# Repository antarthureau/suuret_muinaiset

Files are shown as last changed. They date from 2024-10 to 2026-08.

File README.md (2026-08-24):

# Suuret Muinaiset system (V3)

## Overview

The installation has three units. Each unit is one creature: LONG, SMALL or
SEASHELL. Each unit has a Teensy 4.0 microcontroller.

Each unit plays its own audio file. It drives its own amplifier and speaker. It
also calculates its own LED brightness from the audio signal.

LONG is the leader. It is green, and it has the only RTC. SMALL (yellow) and
SEASHELL (red) are followers.

All three units use the same compiled firmware. At start-up, each unit reads
three hardware ID strap pins. The pin that reads HIGH selects the role.
Therefore the role is not a build option.

The firmware is in `src/teensy_codebase/teensy_code_v3`.

`teensy_code_v1` and `teensy_code_v2` stay in the repository for reference. The
Raspberry Pi 5 and Pure Data system is not in use. Its code stays in `src`.

## Unit hardware

Each unit is an IP65 enclosure. It contains the equipment that follows.

- Teensy 4.0 microcontroller on a custom motherboard. The motherboard connects
  the power, the relays, the LED PWM output, Serial3, the volume potentiometer
  input and the 4-LED status array.
- Teensy Audio Shield with an SGTL5000 codec. The micro SD card slot is below
  the Teensy board. The card holds the WAV file for that unit.
- Dual-channel 150 W audio amplifier (WONDOM AA-AB32221). Each unit uses one
  channel only. If the channel becomes defective, connect the spare channel.
  Do not replace the board immediately.
- 36V DC PSU (LOP-300-36). It supplies the amplifier. Relay 2 switches it.
- 12V DC PSU (PSK-15D-12-T). It supplies the Teensy, the motherboard and the
  LED strip. It is always on.
- 4-relay board (Velleman WPM400). Two relays are in use. Relay 1 connects the
  amplifier output to the speaker. Relay 2 connects the 220V AC supply to the
  36V DC PSU. Two spare relays are on the same board.
- DS3231 RTC module on I2C. LONG only.
- Outdoor speaker (Dayton WP8BT).
- LED strip on the speaker grille. A MOSFET on the motherboard drives it.
  The PWM output of the Teensy controls the MOSFET.

During sleep, only the 12V DC PSU indicator is on.

The enclosure has these connectors:

- USB-A for the upload and the serial console.
- EtherCON for Serial3, on underground CAT6 to the other units.
- A second EtherCON for the PWM and LED output. On LONG it also carries the
  volume potentiometer signal.
- PowerCON for the amplifier output to the speaker.
- 230V AC mains input. Wago connectors distribute it in the enclosure.

A pressure-compensating vent and a silica gel tank keep the humidity and the
pressure stable in each enclosure.

## Site wiring

Each unit is in its own enclosure on site. Underground CAT6 connect the three enclosures.
A custom Y-cable divides the serial run from the leader etherCON to the underground CAT6 lines
connecting to the follower units etherCON.

Each unit gets a 230V AC supply comes to its enclosure.

## Audio signal path

The Teensy reads the WAV file for its unit from the SD card. `config.h` gives
the file names in `cfg::FILE_LONG`, `cfg::FILE_SMALL` and `cfg::FILE_SEASHELL`.
The names on the card are `LONG.WAV`, `SMALL.WAV` and `SEASHELL.WAV`. A FAT
file system ignores the letter case.

The source files are in `src/audio/mono/`. `TESTLOOP.WAV` is also in that
folder for bench tests.

The SGTL5000 codec on the Audio Shield converts the audio. The Audio Shield has
a 3.5 mm TRS minijack output. This output goes to an RCA input on the amplifier
board.

The amplifier output goes through a terminal block to Relay 1. When the unit is
awake, Relay 1 connects the output to a PowerCON socket (NAC3FPX-TRUE1). The
mating plug on the speaker cable outside the enclosure is NAC3M-TRUE1-L.

### Why the audio files have one channel

The WAV files are 16-bit PCM at 44.1 kHz. They have one channel (mono).

The first masters had two channels. The firmware read only channel 0 from them.
This did no damage. But it used more bandwidth than necessary.

The samples in a WAV file are in this sequence: L, R, L, R. Therefore the unit
must read the full file from the SD card to get channel 0. A file with two
channels used 176 KB/s of SD card bandwidth. But it gave only 88 KB/s of audio.

New masters with one channel decreased the necessary bandwidth by 50 percent.
This change corrected a high CPU load and audio noise on site. The correction
was in the audio files, not in the firmware.

The first files with two channels are in `src/audio/stereo/`. Keep them for
reference only. Do not copy them to an SD card.

`src/audio/make_mono.sh` makes the one-channel files again from the two-channel
files. It keeps channel 0 without a change to the samples.

### SD card and interrupts

`AudioPlaySdWav` reads the SD card in the audio interrupt. It does not read the
card in `loop()`. Two results are important:

- A slow main loop does not stop the audio. It makes the light irregular.
- Other code that uses the SD card can cause a conflict with the interrupt.

`AudioEngine::retryInit()` therefore does not operate while audio plays.
`SD.begin()` starts the same card that the interrupt reads.

The Teensy 4.0 has no internal SDIO socket. Therefore the card must be in the
socket of the Audio Shield, on the SPI bus. A slow SD card is the most probable
cause of an audio failure.

## Light signal path

`AudioAnalyzePeak` and `AudioAnalyzeRMS` objects connect to the same playback
stream in the audio object graph. Refer to `AudioEngine`.

Each 25 milliseconds (`cfg::PWM_UPDATE_MS`), the controller reads the current
level. `cfg::PEAK_MODE` selects the peak value or the RMS value. The controller
multiplies the level by a range value (`rangePwm_`). The keys `>` and `<`
change this range during operation. Then the controller writes the result to
the 8-bit PWM output on pin 6.

The PWM frequency is 20 kHz (`cfg::PWM_FREQ_HZ`). This frequency is above the
audible range. The default frequency of the Teensy 4 is approximately 4.5 kHz.
That frequency is audible, and it goes into the audio circuit through the
common ground.

The PWM signal goes on CAT6 through the second EtherCON connector to the LED
daughter board. An IRL520 MOSFET on that board controls the current in the 12V
LED strip. The result is the same as the analog PCB of the first system. But
the firmware calculates it.

## Firmware

### Files

The firmware in use is in `src/teensy_codebase/teensy_code_v3`:

```
config.h            pins, times, status codes and protocol constants
StatusLeds.h/.cpp   4-LED binary status display
Relays.h/.cpp       amplifier and speaker relay sequence
AudioEngine.h/.cpp  SGTL5000 codec, SD card playback, peak and RMS analyzers
RtcClock.h/.cpp     DS3231 clock (leader only)
SerialLink.h/.cpp   addressed frames with a checksum, on Serial3
Controller.h/.cpp   role detection, leader and follower state machines
teensy_code_v3.ino  entry point, makes one Controller
```

The `Controller` object holds one instance of each subsystem. It is the only
global object.

`ledzCtrl.h` and `sysCtrl.h` are also in this folder. They are old files from
V2. No file includes them. They are not part of the firmware in use.

`RTC_setup_code/RTC_setup_code.ino` is a separate sketch. Use it to test or to
program a DS3231 module away from the installation.

### Build

1. Start the Arduino IDE with Teensyduino.
2. Select Tools > Board > Teensy 4.0.
3. Select the port of the unit.
4. Click Upload.

The board selection is important. `Watchdog_t4.h` declares `WDT_T4` and `WDOG1`
for the i.MX RT chip only. Teensyduino keeps the 3.x boards and the 4.x boards
in the same `avr` platform folder. Therefore a build with a Teensy 3.x board
gives this error: `'WDOG1' was not declared in this scope`. The library is
correctly installed, but the header is empty for that board.

All three units use the same compiled sketch.

### Compile-time flags

The flags are at the top of `config.h`.

```
USE_WATCHDOG   1  the hardware watchdog resets the unit after 15 seconds
                  of a hang. Set to 0 only if the WDT_T4 library is absent.
                  It must be 1 on site.
AUDIO_TRACE    0  the leader sends an audio-health line each second while
                  audio plays. Set to 1 for diagnostics only. It must be 0
                  on site.
```

`cfg::AUDIO_MEMORY_BLOCKS` (120) sets the size of the audio buffer pool. One
block is 128 samples, or 2.9 milliseconds of audio. The value is larger than
necessary. This gives protection against a slow read from the SD card.

### Role detection

`Controller::detectRole()` reads the three strap pins one time at start-up:

```
pin 32 HIGH  ->  LEADER (LONG)
pin 30 HIGH  ->  SMALL
pin 28 HIGH  ->  SEASHELL
```

The pins use the internal pulldown resistors. Therefore a disconnected strap
reads LOW. If no pin reads HIGH, the unit becomes the leader and sends a
warning on the USB console.

## Teensy pinout

| Pin | Function |
|---|---|
| 0, 1 | Reserved for USB Serial. Do not connect. |
| 2-5 | Status LEDs 1-4 (binary array, LED 1 = MSB) |
| 6 | PWM output to the LED strip driver |
| 7, 8 | Not in use (Serial2 is possible) |
| 9, 12 | Not in use |
| 10 | SD card CS |
| 11 | SD card MOSI |
| 13 | SD card SCK |
| 14 | Serial3 RX (SMALL and SEASHELL only) |
| 15 | Serial3 TX (LONG only) |
| 16 | Relay 1, speaker |
| 17 | Relay 2, 36V PSU and amplifier |
| 18 | RTC SDA (I2C, LONG only) |
| 19 | RTC SCL (I2C, LONG only) |
| 20 | Audio Shield LRCLK |
| 21 | Audio Shield BCLK |
| 22 / A8 | Volume potentiometer analog input |
| 23 | Audio Shield MCLK |
| 28 | Hardware ID strap, SEASHELL |
| 30 | Hardware ID strap, SMALL |
| 32 | Hardware ID strap, LONG (leader) |

Serial3 and the PWM line go through EtherCON chassis sockets (NE8FDPU-TOP) on
CAT6.

The RJ45 pinout of the serial link is opposite at the two ends of the run.
Therefore the Tx of the leader goes to the Rx of the follower. One end is 1 Rx,
2 GND, 3 Tx. The other end is 1 Tx, 2 GND, 3 Rx. Pins 4 to 8 are not in use.

Refer to page 8 of `documentation/manual/manual v1.0.pdf` before you make a
connector again.

PWM and volume RJ45 on LONG: 1 NC, 2 GND, 3 NC, 4 +3.3V, 5 A8 potentiometer
signal, 6 NC, 7 PWM+, 8 PWM-.

PWM RJ45 on SMALL and SEASHELL: 1 to 6 NC, 7 PWM+, 8 PWM-.

## Serial3 link protocol

The three units share one Serial3 link at 9600 baud. The forward line goes from
the Tx of the leader to the Rx of the two followers. The return line goes from
the Tx of the two followers to the Rx of the leader. Therefore only the return
line is common to more than one transmitter.

Each frame has an address and a checksum:

```
#<addr><cmd><arg>*<XX>\n
```

`addr` is `0` for the two followers, `1` for SMALL, `2` for SEASHELL, or `L`
for the leader. Only status replies use `L`.

`cmd` is one command character. `arg` is an optional short ASCII payload.

`XX` is the XOR of all the characters between `#` and `*`, in two hexadecimal
digits.

`SerialLink::poll()` makes one frame at a time and does not block. It ignores a
frame with an overflow, with no `*`, or with an incorrect checksum. A `#`
character always starts a new frame.

### Command characters

| Char | Command | Notes |
|---|---|---|
| `P` | Play | The leader sends this one time for each round, to keep the units synchronized |
| `X` | Stop | Stops the audio and sets the PWM output to zero |
| `W` | Wake | Does the relay wake sequence: 36V PSU on, then speaker on |
| `S` | Sleep | Does the relay sleep sequence: speaker off, then 36V PSU off |
| `H` | Heartbeat | Leader to followers each 5 seconds. `arg` is `1` or `0` for the awake state |
| `R` | Report request | The leader sends this to one follower. That follower answers one time |
| `s` | Status reply | Follower to leader only. `arg` is `role,awake,playing,cpu_temp` |
| `B` | Reboot | The leader sends this, then each unit resets after 3 seconds |
| `V` | Set volume | `arg` is a value between 0.0 and 1.0 |
| `+` / `-` | Volume up or down | Steps of 0.1 |
| `>` / `<` | PWM range up or down | Steps of 25, between 0 and 255 |
| `K` | Volume knob on or off | Lets the potentiometer control the volume |
| `?` | Help | Prints the command list on the USB console only |

### How the two followers share one line

The two followers transmit on the same return line. Three rules prevent two
transmissions at the same time.

- Only `R` causes a follower to transmit. The follower does all other commands
  and stays quiet.
- The leader never sends `R` to address `0`. It always sends `R` to `1` or to
  `2`. The other follower reads the address, and stops.
- The automatic poll asks SMALL, waits 150 milliseconds
  (`cfg::REPORT_STAGGER_MS`), then asks SEASHELL.

A request and a reply together are approximately 25 milliseconds at 9600 baud.
Therefore the 150 millisecond interval is sufficient.

If two replies do come at the same time, the checksum fails. The leader ignores
the frame. The next automatic poll is 20 seconds later.

## USB serial console

Connect the USB cable to a unit. Then open a serial terminal at 9600 baud. The
Arduino Serial Monitor, PuTTY or other serial tools are all satisfactory.
The enclosure can be open or closed.

This is the primary method to communicate with one unit. It does not use the
Serial3 link.

### Single-key commands

```
P  play          W  wake      R  report    +  volume up     >  PWM range up
X  stop          S  sleep     B  reboot    -  volume down   <  PWM range down
K  volume knob on/off         ?  help
```

On the leader, the keys `P X W S + - > < B` go to the followers first. Then the
leader does the command. Therefore the volume keys and the PWM keys change all
three units together.

The keys `R`, `K` and `?` operate on the local unit only. On a follower, all
keys operate on that follower only.

`R` prints the role, the WAV file name, the RTC time on the leader, the awake
and playing states, the volume, the PWM range, the number of rounds, the codec
and SD card status, and the CPU temperature.

### Line commands

A line command starts with `:`. Enter or a pause of 200 milliseconds completes
it.

Clock commands:

```
:settime YYYY MM DD HH MM SS   set the RTC directly
:synctime                      set the RTC to the compile time of the sketch
:time                          print the RTC time
```

The clock commands are for the leader. On a follower the RTC is not
initialized, and the command does nothing.

`:synctime` is a last option only. The compile time is old by the interval
between the build and the upload.

Follower status commands. The leader accepts these commands only:

```
:small      request a status report from SMALL
:seashell   request a status report from SEASHELL
:status     request a report from the two followers, one after the other
```

The follower answers a moment later. The reply prints on the console of the
leader in this form:

```
Status from SMALL: awake YES, playing NO, CPU 41.7 C
```

The leader also requests these reports automatically each 20 seconds.

### Volume

The volume control is not linear. `AudioControlSGTL5000::volume()` writes the
headphone register of the codec. That register is in steps of 0.5 dB, from
+12 dB to -51.5 dB.

```
1.0  ->  +12.0 dB      0.6  ->  -13.5 dB   (the value on site)
0.9  ->   +6.0 dB      0.5  ->  -20.0 dB
0.8  ->   -0.5 dB      0.3  ->  -32.5 dB
0.7  ->   -7.0 dB      0.1  ->  -45.5 dB
```

Each step of 0.1 is therefore approximately 6.5 dB. A value of 1.0 gives 12 dB
of gain, not the level of the audio file.

The unit does not keep the volume value. At each start-up the volume returns to
`cfg::DEFAULT_VOLUME`.

## Status LED codes

The 4-LED array on each motherboard shows a binary code. LED 1 is the most
significant bit. LED 4 is the least significant bit. In the LEDs column, `1` is
an LED that is on.

| Code | LEDs | Name | Meaning |
|---|---|---|---|
| 1 | 0001 | SLEEP | asleep, normal |
| 2 | 0010 | AWAKE | awake, no audio |
| 3 | 0011 | SD_ERR | no SD card |
| 4 | 0100 | CODEC_ERR | no SGTL5000 codec |
| 5 | 0101 | RTC_ERR | no clock (leader only) |
| 6 | 0110 | LINK_ERR | no heartbeat for 90 seconds (followers only) |
| 7 | 0111 | REBOOT | the unit starts again |
| 8 | 1000 | PLAYING | audio plays |

Code 1 during the sleep hours, and sound and light during the awake hours, are
the normal condition.

### Fault codes at start-up

The unit shows the fault codes SD_ERR, CODEC_ERR and RTC_ERR at start-up only.
It does not keep them on the display.

`setup()` finds these faults. At the end of `setup()`, the unit flashes each
fault code for 4 seconds. Then the normal state display starts.

The flash is necessary. A continuous code looks the same as a normal state
code. Also, the first cycle of `loop()` writes to the LED array immediately.

A unit that operates for some hours therefore shows a normal code. This happens
even if the SD card is defective. To read the fault codes again, start the unit
again. Refer to "Read the fault codes at start-up".

## Daily schedule

The leader reads the RTC each 30 seconds. If the awake state must change, the
leader sends `W` or `S` to the two followers. The heartbeat also carries the
awake state.

`config.h` has `cfg::START_HOUR = 8` and `cfg::END_HOUR = 20`. The units are
awake from 08:00 to 20:00. The printed manual gives the first schedule of 07:00
to 22:00. Correct one of the two documents.

To change the schedule, set `START_HOUR` and `END_HOUR` in `config.h`. Then
upload the firmware to the leader. The followers do not read an RTC. They take
the awake state from the leader.

The units stay energized during sleep. Only the 36V amplifier PSU and the
speaker relay go off. The MCU, the watchdog and the Serial3 link continue for
24 hours each day.

## Diagnostics

Set `AUDIO_TRACE` to `1` in `config.h`. The leader then sends one line each
second while audio plays. The default value is `0`.

```
t=<position ms> mem=<peak audio blocks> cpu=<peak audio ISR load %>
```

Read the output as follows:

- If `mem` increases to the limit of 120, the SD card is too slow.
- If `t` does not increase by about 1000 between two lines, the SD card is too
  slow.
- If `mem` and `t` stay correct during an audio fault, the digital circuit is
  correct. The cause is then in the analog circuit after the codec.

Record the output to a file. Use time stamps. Do not use the monitor window
only. An intermittent fault needs the lines before the event and after the
event. It also needs a count of the events before you make a change.

Set `AUDIO_TRACE` to `0` again after the test.

## Troubleshooting

### Read the fault codes at start-up

1. Connect the USB cable of the unit to a computer.
2. Open the enclosure.
3. Press `B` on the USB console. As an alternative, remove the power. Then
   apply the power again.
4. Look at the LED array during the start-up.
5. The unit flashes each fault code for 4 seconds.
6. If the unit flashes no code, the codec, the SD card and the RTC are
   serviceable.

### Code 3 (SD_ERR): no SD card

1. Make sure that the card is fully in the slot. The slot is below the Teensy
   board.
2. Make sure that the card has a FAT32 file system.
3. Make sure that the card has the correct file name for that unit: `LONG.WAV`,
   `SMALL.WAV` or `SEASHELL.WAV`.
4. Use the files from `src/audio/mono/`. Do not use the files from
   `src/audio/stereo/`.
5. The unit tries to find the card again each 3 seconds. It stops after 20
   tries, or approximately 60 seconds after the start-up. Therefore install the
   card again, then start the unit again.

### Code 4 (CODEC_ERR): no codec

1. Remove the Teensy Audio Shield. Then install it again on the header.
2. Examine the solder joints on the shield and on the header pins.
3. Examine the 3.3V supply to the shield.

### Code 5 (RTC_ERR): no clock

1. Examine the I2C wiring on pins 18 and 19. The leader only shows this code.
2. Examine the DS3231 module.
3. Connect the USB cable. If the leader reports lost power at each start-up,
   replace the coin cell.

### Code 6 (LINK_ERR): no heartbeat

1. Examine the CAT6 cable between the leader and the follower.
2. Examine the Serial3 connections at the two ends. The Tx and Rx pins are
   opposite at the two ends. Pin 2 is GND.
3. Make sure that the leader has power and operates. A follower shows code 6
   if the leader stops.
4. Send `:small` or `:seashell` on the USB console of the leader. If the
   follower answers, the cable is serviceable in the two directions.
5. If the follower does not answer, examine the power and the LED array of that
   follower.

### One unit makes no sound

1. Do the procedure "Read the fault codes at start-up".
2. Make sure that the two PSU indicators are on during the awake hours.
3. Examine the minijack cable from the Audio Shield to the RCA input of the
   amplifier.
4. Press `P` on the USB console. If the unit then plays, the schedule is the
   cause. Refer to "The unit sleeps at the incorrect time".
5. If the amplifier channel is defective, connect the second channel of the
   same board.

### The audio has noise or interruptions

1. Make sure that the SD card has the files from `src/audio/mono/`. A file with
   two channels needs two times more bandwidth.
2. Set `AUDIO_TRACE` to `1` in `config.h`. Then build the firmware and upload
   it.
3. Record the console output to a file for one hour. Use time stamps.
4. Write down the time of each audio fault.
5. Read the trace. Refer to "Diagnostics".
6. If the trace shows that the SD card is too slow, replace the SD card.
7. If the trace stays correct, connect headphones to the minijack output. Then
   listen again.
8. If the noise continues in the headphones, the cause is in the codec or its
   connections. Examine the Audio Shield.
9. If the headphones are correct, the cause is in the amplifier or the speaker.
10. Set `AUDIO_TRACE` to `0` again after the test.

### The unit sleeps at the incorrect time

1. Connect the USB cable to the leader.
2. Send `:time` on the USB console.
3. If the time is incorrect, send `:settime YYYY MM DD HH MM SS` with the
   correct values.
4. If the leader reports lost power at each start-up, replace the DS3231 coin
   cell.
5. Make sure that `START_HOUR` and `END_HOUR` in `config.h` are correct.

### Relay problems

1. Two of the four relays are in use. Relay 1 is the speaker. Relay 2 is the
   36V PSU.
2. If one relay becomes defective, connect one of the two spare relays on the
   same board.
3. If all four relays become defective, replace the board.

### The unit does not answer on USB, but the LEDs operate

1. The watchdog resets the unit after 15 seconds of a hang. Wait 20 seconds.
2. If the unit stays locked, the cause is probably the hardware. The main loop
   does not block.
3. Examine the USB cable and the USB connector.

### The build stops with an error

1. If the error is `'WDOG1' was not declared in this scope`, look at the board
   selection. It must be Teensy 4.0.
2. If the board selection is correct, install the WDT_T4 library. As an
   alternative, set `USE_WATCHDOG` to `0` for a test build.
3. Look at the full path in the error message. Make sure that it is the path of
   your local repository. A different copy of the sketch can have different
   values in `config.h`.
4. Close the Arduino IDE and open it again. The IDE can keep an old object file
   in its cache.

## Required toolkit

- Flat screwdriver 3 mm for the terminal blocks.
- Flat screwdriver 6 mm and Phillips 6 mm for the screws of the enclosures and general use.
- Multimeter for voltage and continuity tests: 230V AC, 12V DC, 36V DC.
- Phillips 000 and 00 screwdrivers, and 4 mm and 4.5 mm hex keys.
- Anti-static wrist strap.
- Wago connectors, wire and crocodile clips for temporary connections.
- 3.5 mm stereo headphones to listen to the Audio Shield output directly.
- A computer with a USB-A port, the Arduino IDE with Teensyduino, and a serial
  monitor.
- A long CAT6 test cable, or a cable tester, for the underground runs.

For workshop tests:

- An Arduino Uno R3 to program or test a DS3231 module. Refer to
  `RTC_setup_code`.
- An oscilloscope for signal analysis.
- A spare Teensy 4.0 to exchange components.
- A bench power supply for isolated tests.

## Warranty and support

Warranty period: 04.06.2025 to 04.06.2026.

Support during the warranty period: ahureau@pm.me, or the support technician on
site in Turku. The usual answer time is 24 to 48 hours.

## References

- `documentation/manual/manual v1.0.pdf` is the full technical manual. It has
  the block diagrams and the connector pinout charts. This README comes from
  that manual.
- `documentation/editable doc.drawio` and `editable doc v2.drawio` are the
  editable source diagrams.
- `documentation/3D prints stl files/` has the enclosure gaskets and the
  mounting parts.
- (UNUSED)`documentation/schematics v2.pdf` is for the analog envelope-follower PCB of
  the first Raspberry Pi system. It does not apply to this Teensy system. The
  firmware now calculates the light envelope.

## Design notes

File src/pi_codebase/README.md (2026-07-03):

# suuret_muinaiset system (V2)
## Overview
The installation runs on a single Raspberry Pi 5, replacing the previous three-unit Teensy-based system (LONG, SMALL, SEASHELL).
One Raspberry Pi 5 running Pure Data plays three audio files simultaneously (main.pd in pd_codebase), one file per creature, and drives both the speakers and the LED lighting (sound-to-light analog circuit) for all three units.

## Hardware/Software Requirements
Raspberry Pi 5 with onboard RTC and battery, used for the daily sleep/wake cycle.

Pure Data (Pd), run headless via pd -nogui. Login at desktop activated, so troubleshooting with mouse, keyboard and HDMI screen is possible.

zexy external library (installed via Deken), loaded in the patch with [declare -lib zexy].

HiFiBerry 8-channel DAC card, three of its outputs used for the three audio channels. LONG on DAC3, SMALL on DAC1, SEASHELL on DAC2, and DAC5/6 is a headphone out with a sum of all creatures.

Neutrik transformers, used twice per channel: once locally to balance the signal for transmission, and once at each remote creature to convert back to unbalanced before the amp.

Cat6 cable, run underground, carrying the balanced signal to each creature's site.

Amplifier and speaker at each creature site.

Custom analog PCB per creature: envelope-follower circuit based on TL072 and TL071 op-amps with an IRL540 MOSFET, converting that creature's audio amplitude into LED strip brightness.

12V LED strip per creature (final installation voltage).

2× SMPS per unit: 36VDC for the amplifier and 12VDC for the LED circuit PCB and LED strips. On the LONG unit, the PCB also carries an on-board Traco DC-DC converter providing 5V to power the Raspberry Pi from the 12V supply rail; this component is not populated on the SMALL and SEASHELL boards.

## Signal path

Pd plays three looping audio files, one per creature, out through three channels of the HiFiBerry DAC. Each unbalanced line passes through a Neutrik transformer to balance it for the long underground Cat6 run to that creature's location. At the far end, a second Neutrik transformer converts the signal back to unbalanced before it reaches that creature's amplifier and speaker.

## Audio-to-light circuit

Each creature has a custom PCB (ordered from JLCPCB) that converts its audio channel's amplitude into a brightness level for its 12V LED strip, independently of the speaker signal path.

Signal path through the circuit:

Audio arrives at an RCA connector and passes through a 1µF capacitor (AC coupling, blocking any DC offset) into a bias network — a 100kΩ/100kΩ resistor divider sets a +6V virtual midpoint from the 12V supply, centering the signal for single-supply op-amp operation.

The first TL072 half (U1A) buffers the input. The second TL072 half (U1B) amplifies the signal; gain is set by a 1MΩ feedback resistor and a 100kΩ trimmer potentiometer.

A 1N4148 diode half-wave rectifies the amplified AC signal into a positive envelope voltage. Two 100kΩ trimmer potentiometers control attack time (how fast the envelope rises with loud transients) and decay time (how slowly it falls when sound stops). A 4.7µF capacitor holds the peak level between transients.

A TL071 (U2) buffers the envelope voltage, isolating the capacitor from the output stage.

An IRL540 power MOSFET (Q1) is driven through a 100Ω gate resistor. A 10kΩ pull-down resistor on the gate ensures the MOSFET turns fully off when the signal drops to zero. The MOSFET switches the 12V LED strip current in proportion to the envelope voltage.

Power input is protected against reverse polarity by a 1N4007 diode. On the LONG unit PCB only, a Traco DC-DC converter provides a regulated 5V output used to power the Raspberry Pi from the 12V supply rail. This component is not populated on the SMALL and SEASHELL boards.

## Pure Data patch

Main patch: pd_codebase/main.pd, run in nogui mode.

Loops playback continuously; prints a status line at the start of each loop, captured by the terminal/log rather than the patch itself doing timestamping.

Elapsed time within each loop is tracked via zexy's realtime object, converted to mn:ss:ms via expr and sprintf, and reset at the start of each playback cycle (roughly every 6 minutes).

Remote control of the running patch (e.g. via Pd's netreceive) is possible but not yet implemented.

## Sleep/Wake schedule

The Pi sleeps and wakes itself daily using its onboard RTC and battery, fully powering off rather than suspending. This requires POWER_OFF_ON_HALT=1 in the bootloader config, checked with sudo rpi-eeprom-config.

The script /home/mike/sleep_pi.sh sets the next wake alarm and shuts the system down:

```
#!/bin/bash
echo 0 > /sys/class/rtc/rtc0/wakealarm
echo $(date -d "tomorrow 08:00" +%s) > /sys/class/rtc/rtc0/wakealarm
/usr/sbin/shutdown -h now
```

It must use the full path /usr/sbin/shutdown, since cron runs with a minimal PATH that doesn't include /usr/sbin.

The script is triggered daily by root's crontab (sudo crontab -e). Current entry: 00 22 * * * /home/mike/sleep_pi.sh, meaning cron fires the sleep script at 22:00, and the script sets the wake alarm for 08:00 the next day. When changing sleep or wake times, update both the cron line and the date string in the script together, leaving a few minutes of margin between the cron trigger and the wake target.

### Autostart

The Pi boots into the desktop automatically (autologin enabled via raspi-config, System Options, Boot/Auto Login, Desktop Autologin). On desktop load, labwc reads ~/.config/labwc/autostart, which contains:

```
lxterminal -e "/usr/bin/pd -nogui -alsa -alsaadd snd_rpi_hifiberry_dac8x -outchannels 8 -noadc -nomidi -r 44100 -blocksize 512 -audiobuf 25 -noprefs -open /home/mike/Documents/suuret_muinaiset/pd_codebase/main.pd" &
```

The trailing & is required so labwc doesn't wait for Pd to exit before finishing desktop startup. This opens a visible terminal running Pd, so a technician with a screen and keyboard can see live output directly, while remote access via Pi Connect or SSH works the same regardless.

### Daily cycle

08:00, Pi wakes, boots to desktop, Pd autostarts via labwc.

08:00 to 22:00, Pd runs continuously, looping playback through all three channels.

22:00, cron fires sleep_pi.sh, which sets the next wake alarm and shuts the Pi down fully.

22:00 to 08:00, Pi is fully powered off.

## Network Access

The Pi has three network interfaces, each serving a different purpose:

wlan0 — onboard WiFi, configured as a permanent hidden-SSID access point. Used for on-site wireless maintenance without opening the enclosure. No internet access.

eth0 — wired ethernet, static IP. Used for a direct on-site cable connection when WiFi isn't practical or reliable enough.

wlan1 — USB WiFi dongle (D-Link AC13U). Connects outward to an external network (e.g. a phone hotspot) to bring the Pi online, which is required for Pi Connect remote support.

Pick the option below that matches your situation.

### Option 1: WiFi access point (on-site, no cable needed)

SSID: HUOLTO-NETT (hidden, not broadcast)
Security: WPA2
Password: see project credentials
Static IP: 10.42.0.1

On your laptop, open WiFi settings and manually join the hidden network HUOLTO-NETT (you'll need to enter the SSID by name since it won't appear in scan results). Set your laptop's WiFi interface to a static IP on the same subnet, e.g. 10.42.0.50 / 255.255.255.0.

Then:
```
ssh mike@10.42.0.1
```

### Option 2: Wired ethernet (on-site, direct cable)

Static IP: 10.42.1.2

Connect a Cat6 cable directly between your laptop's ethernet port (or USB/Thunderbolt-to-RJ45 adapter) and the Pi's ethernet port. Set your laptop's ethernet interface to a static IP on the same subnet, e.g. 10.42.1.50 / 255.255.255.0.

Then:
```
ssh mike@10.42.1.2
```

Useful when WiFi conditions on-site are poor, or as a fallback if the access point config is ever broken and needs fixing from scratch.

### Option 3: Internet access for remote support (wlan1)

If remote support from the development team is needed, wlan1 must be connected to an internet-providing WiFi network (e.g. a phone hotspot). Get in touch with the development team in advance so everyone involved can plan for a maintenance session.

Once you have SSH access via Option 1 or 2 above, connect wlan1:
```
sudo nmcli device wifi connect "hotspot_name" password "hotspot_password" ifname wlan1
```

If the hotspot password contains special characters, use single quotes instead of double quotes around it, otherwise the shell may misinterpret characters like $ or ( ) before nmcli ever sees them:
```
sudo nmcli device wifi connect "hotspot_name" password 'hotspot_password' ifname wlan1
```

If the target network doesn't show up in a scan (common with iPhone hotspots, which only broadcast while the Personal Hotspot screen is actively open), create the connection manually instead:
```
sudo nmcli connection add type wifi ifname wlan1 con-name "hotspot_name" ssid "hotspot_name"
sudo nmcli connection modify "hotspot_name" wifi-sec.key-mgmt wpa-psk
sudo nmcli connection modify "hotspot_name" wifi-sec.psk 'hotspot_password'
sudo nmcli connection up "hotspot_name"
```

Pi Connect becomes available to the development team automatically once wlan1 has internet access. Check status with:
```
rpi-connect status
```

Note: the D-Link dongle is currently running on its default in-kernel driver (rtl8xxxu), not the DKMS RTL8192EU driver. This works for now but hasn't been validated for long-term stability — see Key learnings for follow-up.

## Pure Data - Command Line Options

The installation launches Pd headless with explicit audio configuration flags set in the autostart command, rather than relying on Pd's saved preferences. This ensures consistent behaviour across reboots and system changes.

Current launch flags:

```
pd -nogui -alsa -alsaadd snd_rpi_hifiberry_dac8x -outchannels 8 -noadc -nomidi -r 44100 -blocksize 512 -audiobuf 25 -noprefs -open /home/mike/Documents/suuret_muinaiset/pd_codebase/main.pd
```

Flag summary:

| Flag | Purpose |
|---|---|
| `-nogui` | Headless operation |
| `-alsa` | Force ALSA audio API |
| `-alsaadd snd_rpi_hifiberry_dac8x` | Pin HiFiBerry DAC8x by name (stable across reboots) |
| `-outchannels 8` | Open all 8 DAC channels |
| `-noadc` | Disable audio input |
| `-nomidi` | Disable MIDI |
| `-r 44100` | Sample rate |
| `-blocksize 512` | DSP block size in samples |
| `-audiobuf 25` | Audio I/O buffer in milliseconds |
| `-noprefs` | Ignore saved Pd preferences; command line is authoritative |

Full reference for Pd command line options: https://puredata.info/docs/faq/commandline

## Toolkit required for maintenance

Screwdrivers to open/close boxes and fasten terminal blocks: flat 3mm, flat 6mm, Philips 6mm.

Multimeter to test voltage, current, and continuity.

Wago connectors and crocodile cables for temporary test connections.

A pair of headphones with minijack, to test audio output directly from the Pi (DAC 5/6).

HDMI cable, screen, keyboard and mouse, for direct access to the Pi's desktop on site.

Computer or laptop for SSH/Pi Connect access when remote troubleshooting is preferred over an on-site screen.

Ethernet cable (Cat6) and a USB/Thunderbolt-to-RJ45 adapter if your laptop lacks a built-in ethernet port, for wired on-site access.

A smartphone with hotspot to connect the Pi to the wifi, allowing remote control via Pi-Connect.

Long Cat6 testing cable or cable tester, for diagnosing the underground transformer runs.

Gaffer tape, zip ties, and miscellaneous crimping tools can be helpful.

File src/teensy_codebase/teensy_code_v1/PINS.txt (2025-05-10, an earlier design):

PINS:
    0 x (must be NC, used for USB Serial)
    1 x (must be NC, used for USB Serial)
    2 LED_1
    3 LED_2
    4 LED_3
    5 LED_4
    6 PWM_OUT (LED strip control)
    7 x (can be used as receiver for Serial2)
    8 x (can be used as transmitter for Serial2)
    9 x
    10 SDCARD_CS_PIN (SD card)
    11 SDCARD_MOSI_PIN (SD card)
    12 x
    13 SDCARD_SCK_PIN (SD card)
    14 RX3 (receive serial on SM/SS, x on LO)
    15 TX3 (send serial on LO, x on SM/SS)
    16 REL_2 (relay speaker)
    17 REL_1 (relay PSU/amp)
    18 SDA0 (RTC on LO, x on SM/SS)
    19 SCL0 (RTC on LO, x on SM/SS)
    20 LRCLK1 (audio)
    21 BCLK1 (audio)
    22 VOL_CTRL_PIN (analog volume ctrl)
    23 MCLK (audio)
    28 PLAYED_ID (2, SS)
    30 PLAYER_ID (1, SM)
    32 PLAYER_ID (0, LO)

  CODES:
    0 x
    1 asleep
    2 awake
    3 unable to access SD
    4 SGTL not found
    5
    6
    7 system reboot in 5seconds
    8 audio playback
    9
    10
    11
    12
    13 SGTL5000 not found
    14
    15

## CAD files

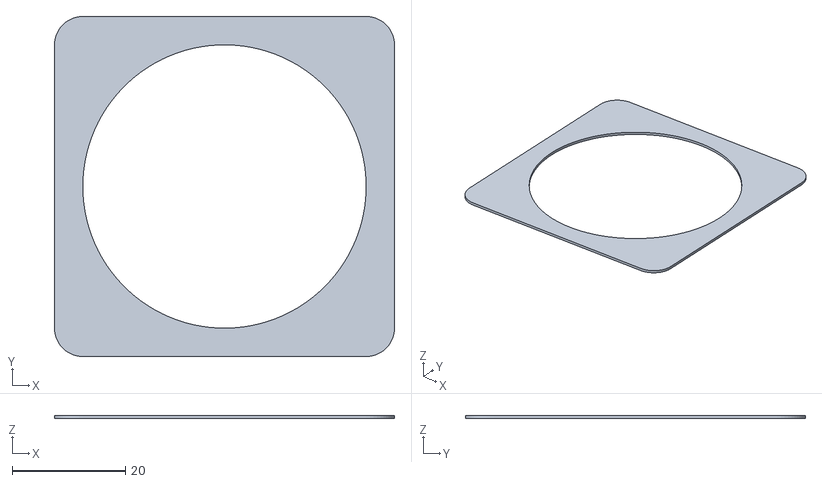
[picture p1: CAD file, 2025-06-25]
documentation/3D prints stl files/Sillica Gel Tank TPU Gasket.stl
60.0 x 60.0 x 0.6

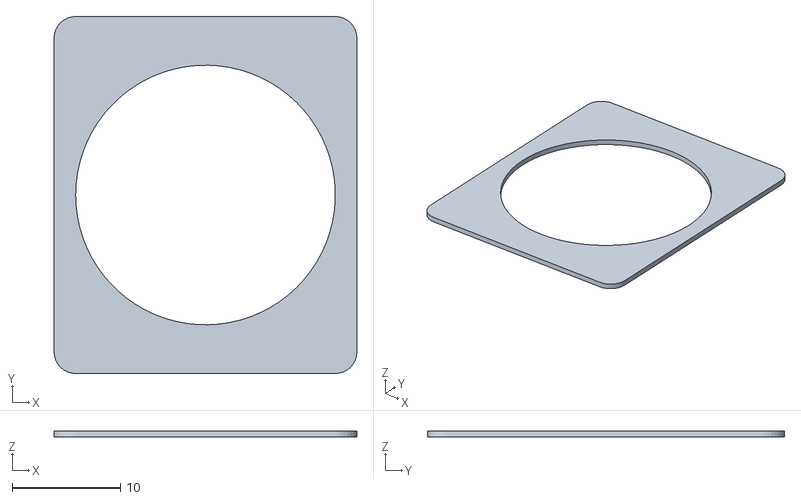
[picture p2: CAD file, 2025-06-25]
documentation/3D prints stl files/Ethercon TPU gasket.stl
28.0 x 33.0 x 0.6

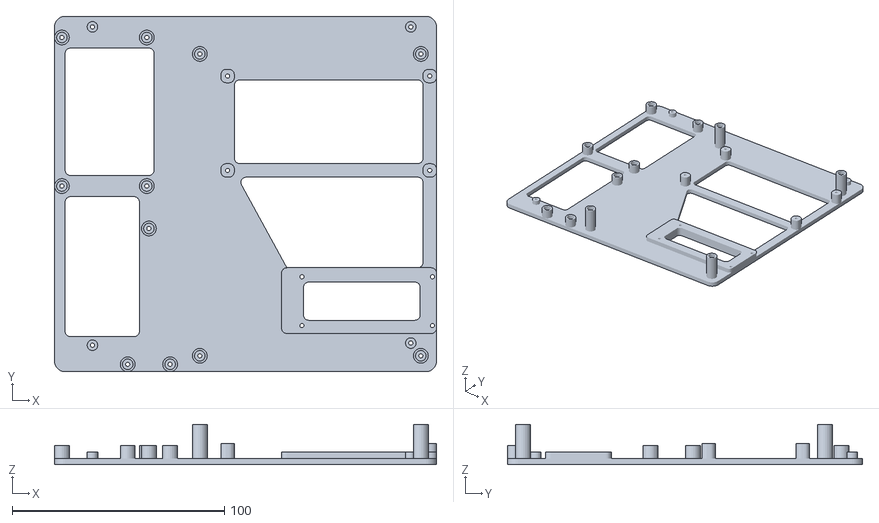
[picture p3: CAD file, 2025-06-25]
documentation/3D prints stl files/PETG Mounting Plate.stl
180.0 x 167.5 x 19.0

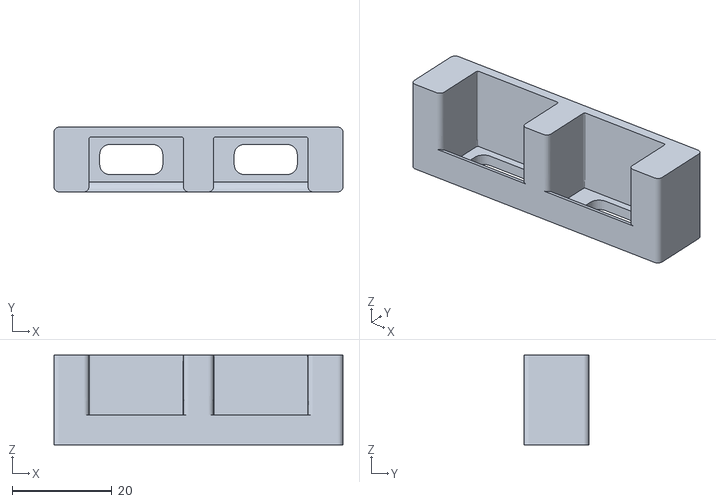
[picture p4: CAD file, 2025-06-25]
documentation/3D prints stl files/Double 3-ways Wago holder.stl
58.0 x 13.0 x 18.0

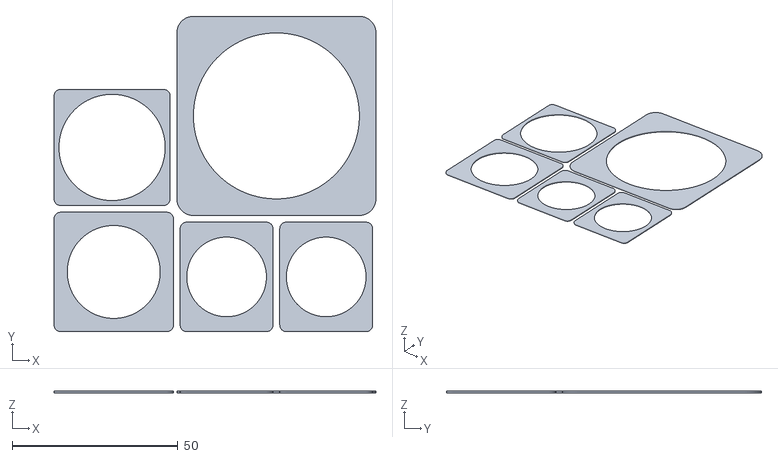
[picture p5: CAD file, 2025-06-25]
documentation/3D prints stl files/All TPU Gaskets.stl
97.0 x 95.0 x 0.6

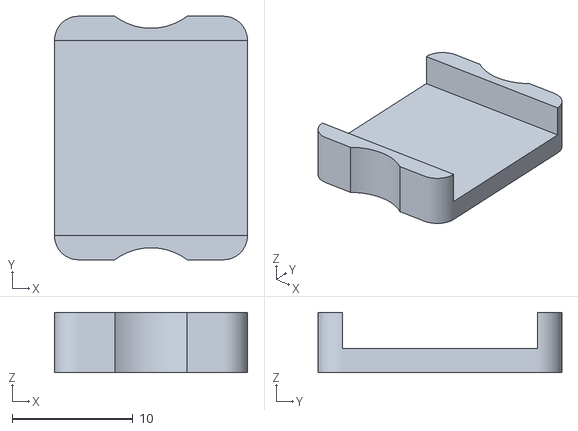
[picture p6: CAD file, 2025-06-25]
documentation/3D prints stl files/Motherboard relays connector cover.stl
16.0 x 20.2 x 5.00

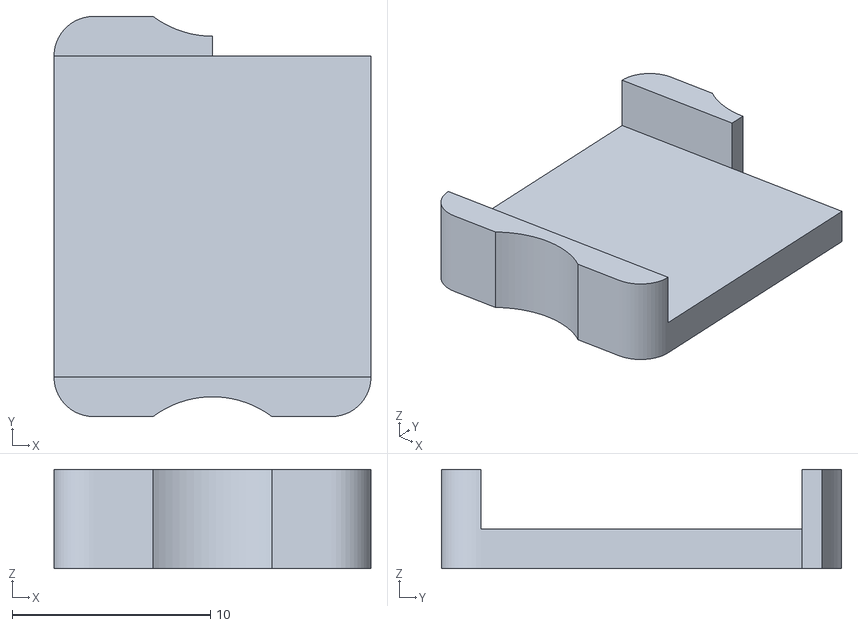
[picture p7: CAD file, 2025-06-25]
documentation/3D prints stl files/Relay board connector cover.stl
16.0 x 20.2 x 5.00

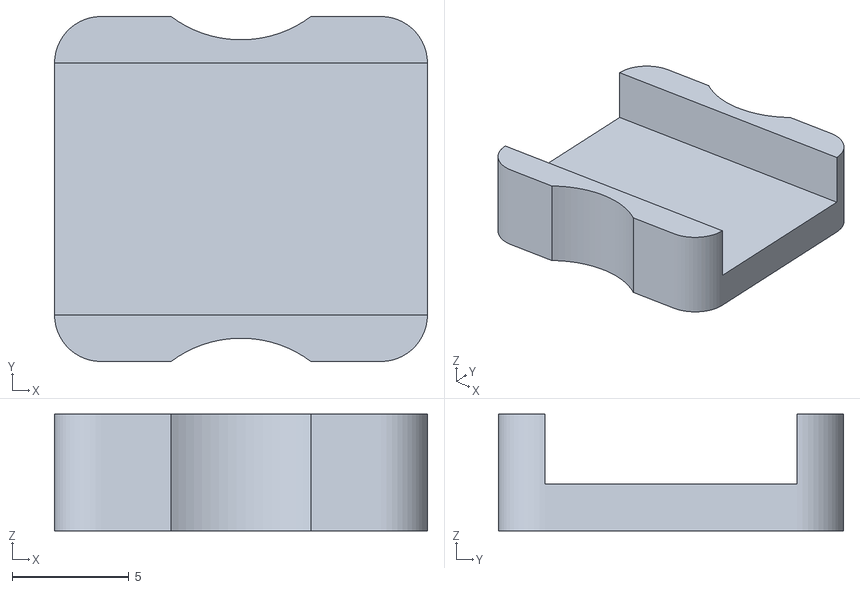
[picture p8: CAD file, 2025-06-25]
documentation/3D prints stl files/RTC cable connector cover.stl
16.0 x 14.8 x 5.00

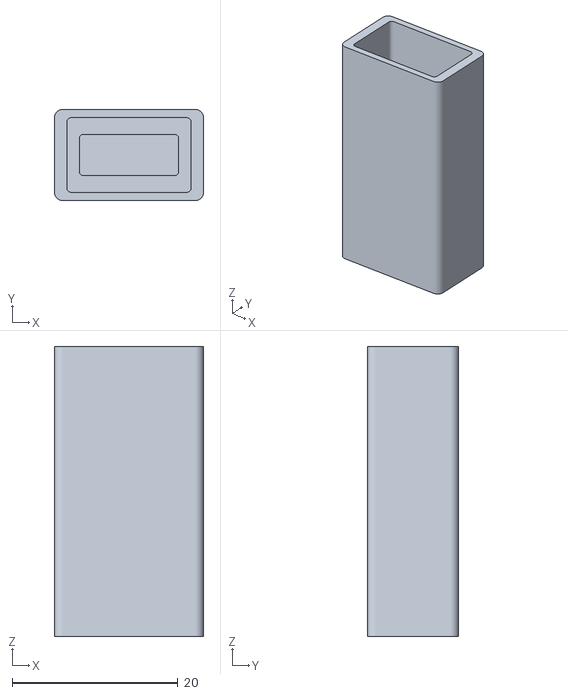
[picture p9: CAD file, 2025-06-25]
documentation/3D prints stl files/USB-A TPU cover.stl
18.0 x 11.0 x 35.0

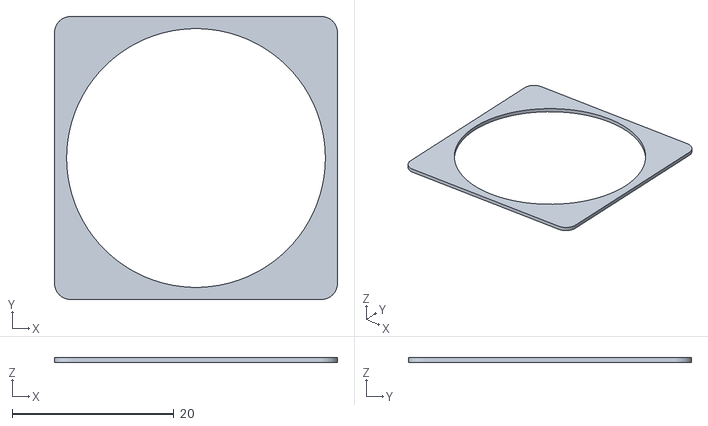
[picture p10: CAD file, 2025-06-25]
documentation/3D prints stl files/Pressure Vent TPU Gasket.stl
35.0 x 35.0 x 0.6

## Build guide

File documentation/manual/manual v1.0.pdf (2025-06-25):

SUURET MUINAISET TECHNICAL MANUAL Version 1.0

Installation: Suuret Muinaiset
Artists: Joel Steenros, Jesse Kitinoja
Technical Design: Antoine Arthur Hureau / Ant Art Enkeltpersonforetak Contact: ahureau@pm.me, Bergen, Norway
GitHub: https://github.com/antarthureau/suuret_muinaiset
===========================================

# ELECTRICAL SAFETY WARNING

ALWAYS disconnect 220V AC power before opening any enclosure
ONLY power units with open enclosures when necessary safety precautions are taken
Use proper lockout/tagout procedures during maintenance
Ant Art Enkeltpersonforetak is not liable for accidents due to misuse of the equipment or misinterpretation of these instructions
===========================================

QUICK START FOR TECHNICIANS

Closed enclosure:

1. Connect USB cable to monitor serial output to communicate with units

Open enclosure (powered on):

1. Verify 12V and 36V PSU indicator LEDs are illuminated, test voltages them with multimeter (230V AC, 12V DC, 36V DC)
2. Verify continuity on relays and all screw terminals
3. Refer to system status or error codes using the 4-LEDs array
4. See troubleshooting flowchart

Parts that are prone to failure earlier are the audio amplifier and the relays. If one channel of the amplifier fails, use the second channel. If both channels fail, replace amplifier board. There are only 2 relay in used on the 4 relays board, if one relay fail, use another one and
re-cable properly between the motherboard and the relay board. If all fail, replace the relay board.

SYSTEM OVERVIEW

This system consists of 3 units playing sound and controlling light for the installation Suuret Muinaiset. In the installation, 3 concrete sculptures/creatures communicate through sound and light:

LONG (Green) - Leader unit (ID0)
SMALL (Yellow) - Follower unit (ID1)
SEASHELL (Red) - Follower unit (ID2)

Each unit consists of:

IP65-rated enclosure containing:
Teensy 4.0 microcontroller
Custom motherboard with I/O connections Official Teensy Audio Shield
Dual-channel 150W audio amplifier
36V DC PSU (audio power)
12V DC PSU (control/LED power) Outdoor-rated speaker (Dayton WP8BT)
LED strip mounted on speaker grille

Programming Environment: Arduino + Teensyduino frameworks with external libraries

Communication Architecture
The 3 units communicate via Software Serial3 (TTL signal over underground CAT6 cable). The implementation uses a leader-follower pattern:

Leader unit (LONG) sends synchronized commands to both followers
Followers can report status back to leader when requested
Each unit can be independently controlled via USB serial connection
All units run identical firmware; behavior determined by hardware ID pins

Automated Operation
The leader unit includes an RTC module ensuring:

Puts system to sleep at 22:00 (36V DC off during that time) Wakes system at 07:00 (36V DC on during that time) Forwards sleep/wake commands to follower units

Di ti

Diagnostics
Each motherboard features a 4-LED binary array displaying values 0-16 for system status and troubleshooting.

NORMAL OPERATION INDICATORS

LED Array: Binary 1 (0001) = Normal operation
Audio: periodic sound sequence as programmed (loops every 6mn during wakeup) Light: periodic light sequence as programmed (loops every 6mn during wakeup) Power: Both PSU indicator LEDs illuminatedduring wakeup, only 12V DC during sleep. Sleep Schedule: 22:00 - 07:00 (adjustable via reprogramming)
Serial Output: Regular status messages, no errors

REQUIRED TOOLS

Basic Maintenance:

Flat screwdriver 3mm - terminal blocks

Flat screwdriver 6mm - enclosure fasteners

Phillips screwdriver 6mm - general use

Multimeter - voltage/continuity testing

Board-Level Service:

Phillips 000 or 00 - PCB work

Hex key 4mm - motherboard mounting

Hex key 4.5mm - module mounting

Anti-static wrist strap

On-site testing Equipment:

Wago connectors - temporary connections

Crocodile clips - testing leads

3.5mm stereo headphones - audio testing

Computer with:

USB-A port

Arduino IDE + Teensyduino installed

Serial monitor software (PuTTY, Arduino Serial Monitor, etc.)

Advanced Diagnostics: (troubleshooting in workshop environment)

Arduino UNO R3 - RTC module reprogramming and logic testing/analysis

Oscilloscope - signal analysis

Spare Teensy 4.0 - component swap testing

Bench power supply - isolated testing

WARRANTY AND SUPPORT

Warranty Period: 04.06.2025 - 04.06.2026
Support Contact during warranty period: ahureau@pm.me (designer) / artturi.elovirta@gmail.com (support technician in Turku) Response Time: 24-48 hours

In the following pages, the units are detailed through comprehensive diagrams, pinout references, and step-by-step maintenance procedures.

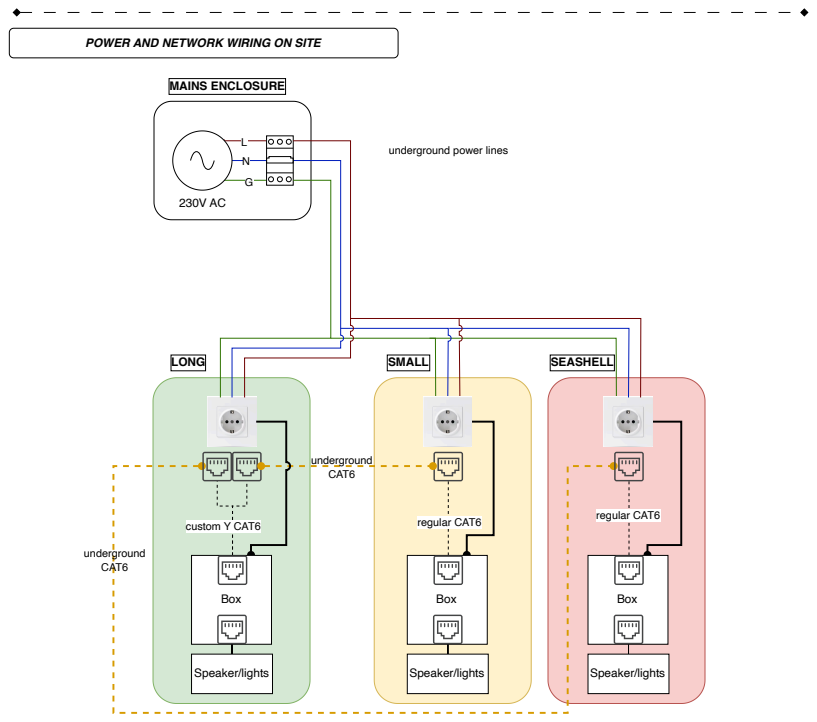
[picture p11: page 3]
underground CAT6; custom Y CAT6; Speaker/lights; regular CAT6; LONG; SMALL; SEASHELL; MAINS ENCLOSURE; Box

POWER AND NETWORK WIRING ON SITE

underground power lines

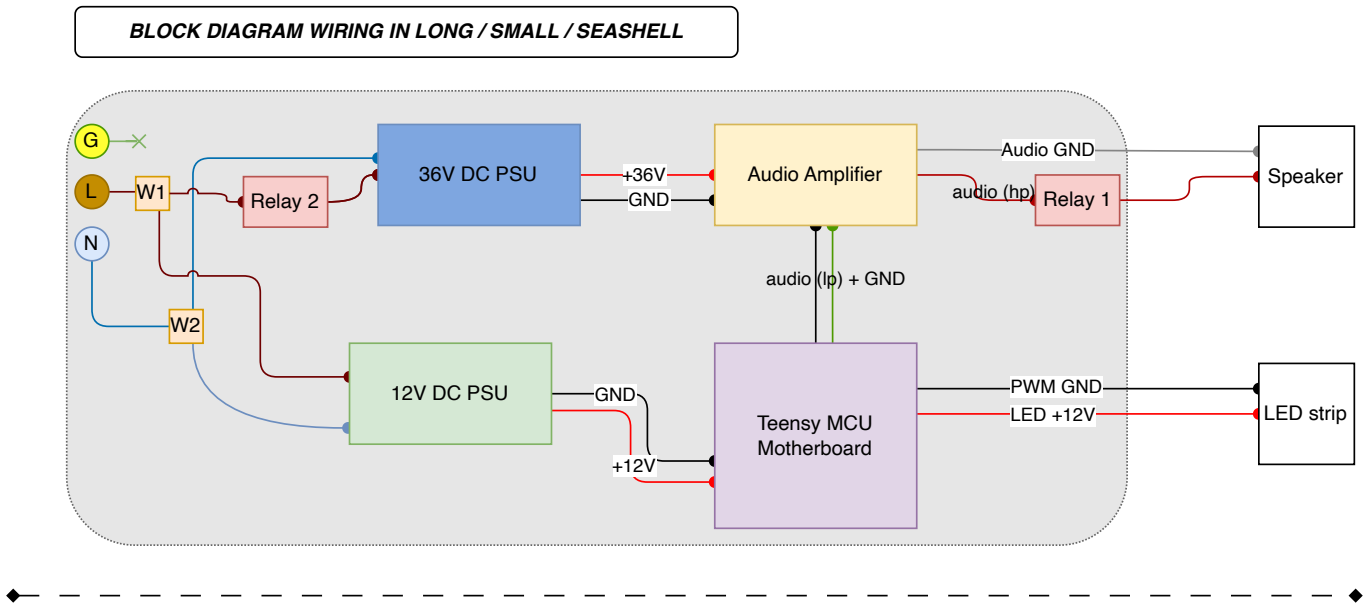
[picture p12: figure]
+36V GND; GND; audio (lp) + GND; PWM GND LED +12V Teensy MCU; Motherboard; Audio GND; audio (hp); Audio Amplifier; LED strip; Relay 1; 36V DC PSU; Speaker; 12V DC PSU; Relay 2

BLOCK DIAGRAM WIRING IN LONG / SMALL / SEASHELL

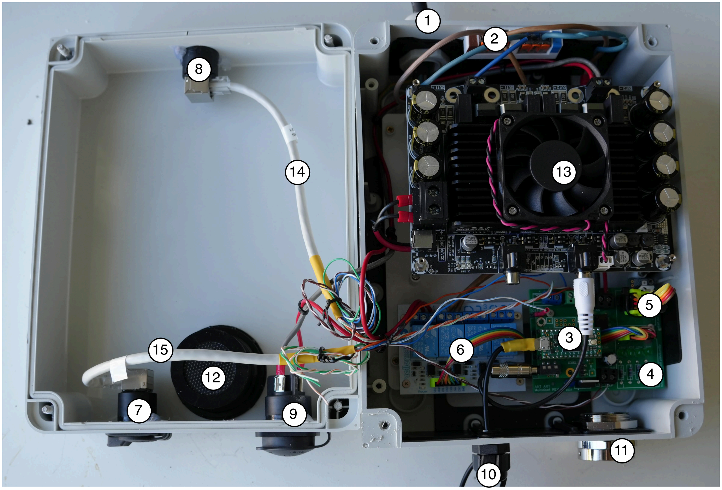
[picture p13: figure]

1. Main power input (220V AC)
2. Wagos for 220V AC distribution/splitting
3. Teensy 4.0 MCU
4. MCU Motherboard with different I/O and LED array
5. RTC module (LONG player only)
6. Relay board to switch certain connections on/off
7. EtherCON chassis connector serving as PWM output to LED strip
8. EtherCON chassis connector serving as a serial communication port
9. PowerCON chassis connector serving as audio output to speaker
10. USB Cable to upload code and communicate with the MCU
11. Pressure compensating vent to maintain stable pressure and temperature in unit
12. Sillica gel tank to absord humidity in unit
13. Dual channel 150W audio amplifier
14. CAT6 cable used to link motherboard to the chassis connector (Serial)
15. CAT6 cable used to link motherboard to the chassis connector (PWM)

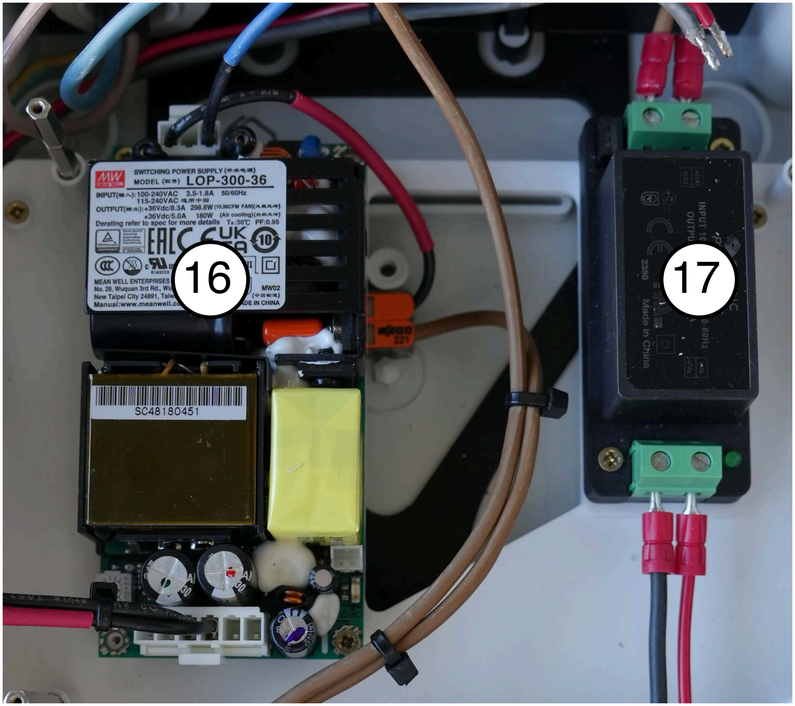
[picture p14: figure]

16. 220V AC to 36V DC PSU
17. 220V AC to 12V DC PSU

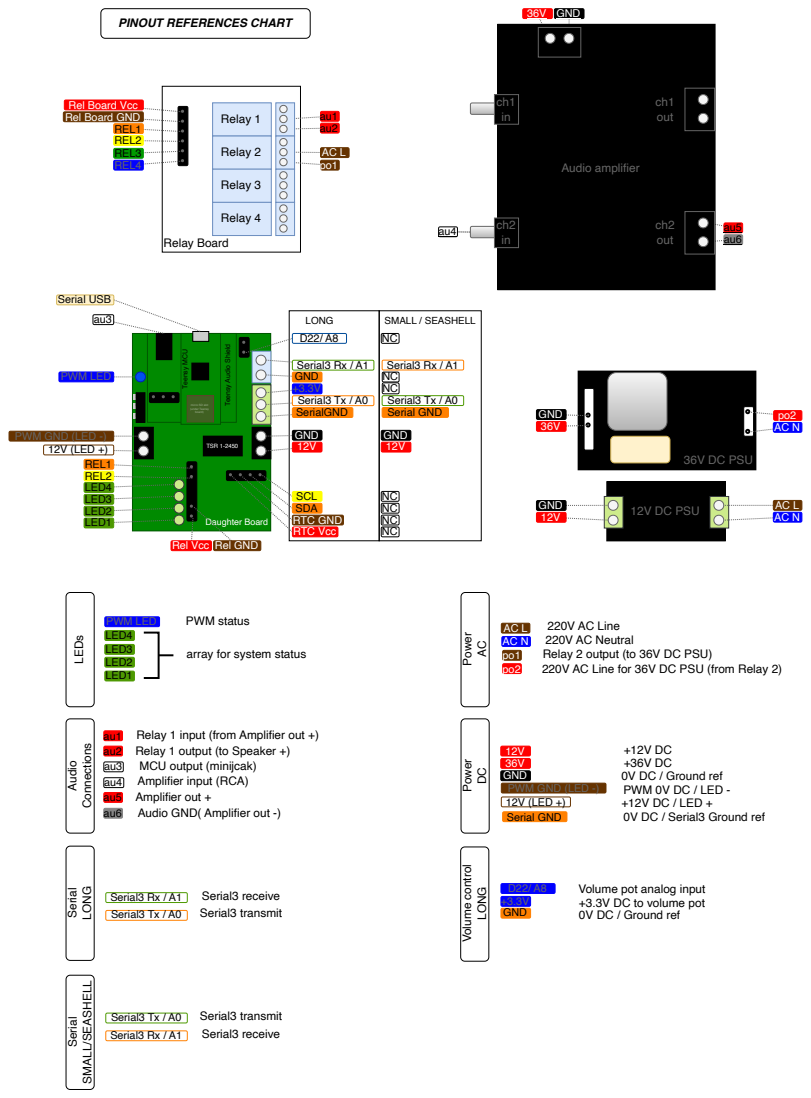
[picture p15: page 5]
Relay Board; 12V (LED +); PWM GND (LED -); LED1; LED2; LED3; LED4; PWM LED; GND; Serial GND; Serial; LONG; Power; Volume control; PWM status; Serial3 Tx / A0; Serial3 Rx / A1; Serial3 receive; Serial3 transmit; SMALL/SEASHELL; Daughter Board; Teensy MCU; TSR 1-2450; IRL-520; Serial3 Tx / A0 Serial GND; GND 12V; SerialGND; GND +3.3V; SMALL / SEASHELL; Rel Vcc; REL2; REL1; Rel GND; SCL SDA; Serial USB; REL4; REL3; RTC Vcc; RTC GND; 36V DC PSU; GND 36V; 36V GND; Relay 1; Relay 2; Relay 3; Relay 4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

PINOUT REFERENCES CHART

Rel Board Vcc
Rel Board GND

Teensy Audio Shield

micro SD slot
(under Teensy
board)

PWM GND (LED -)

12V DC PSU GND

220V AC Line
220V AC Neutral
Relay 2 output (to 36V DC PSU)
220V AC Line for 36V DC PSU (from Relay 2)

LEDs Audio Connections

array for system status

Relay 1 input (from Amplifier out +)
Relay 1 output (to Speaker +)
Amplifier input (RCA)
Amplifier out +
Audio GND( Amplifier out -)

0V DC / Ground ref
PWM 0V DC / LED -
+12V DC / LED +
0V DC / Serial3 Ground ref

MCU output (minijcak)

Volume pot analog input
+3.3V DC to volume pot

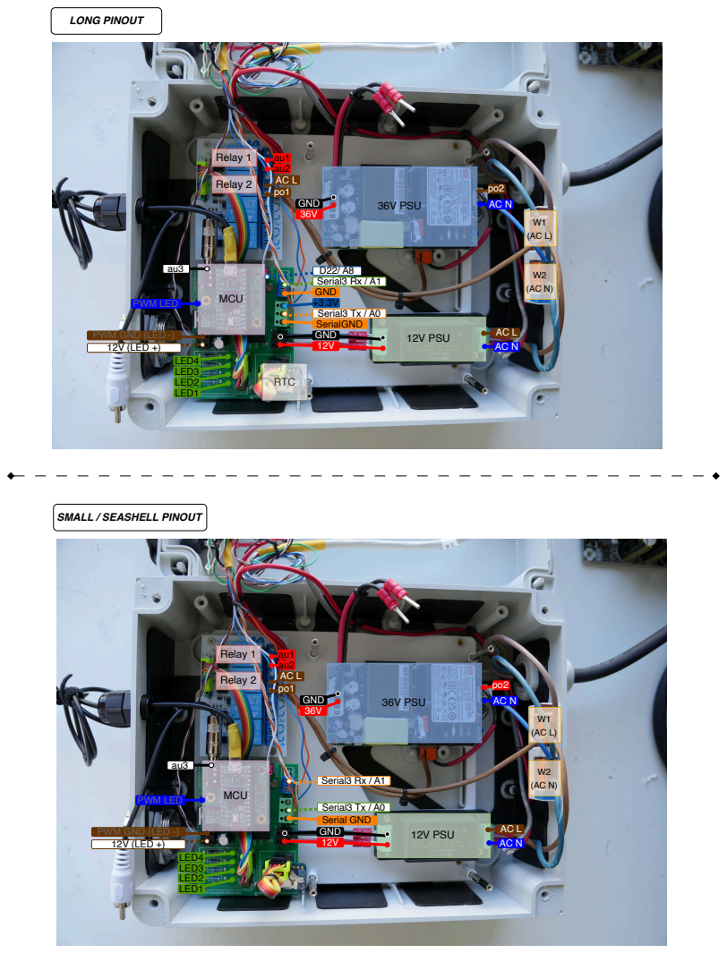
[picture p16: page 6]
36V PSU; 12V PSU; Relay 1; Relay 2; MCU; GND; 12V (LED +); Serial3 Tx / A0; Serial3 Rx / A1; SerialGND; GND +3.3V; GND 36V; LED1; LED2; LED3; LED4; PWM LED; LONG PINOUT; Serial3 Tx / A0 Serial GND; RTC

PWM GND (LED -)

SMALL / SEASHELL PINOUT

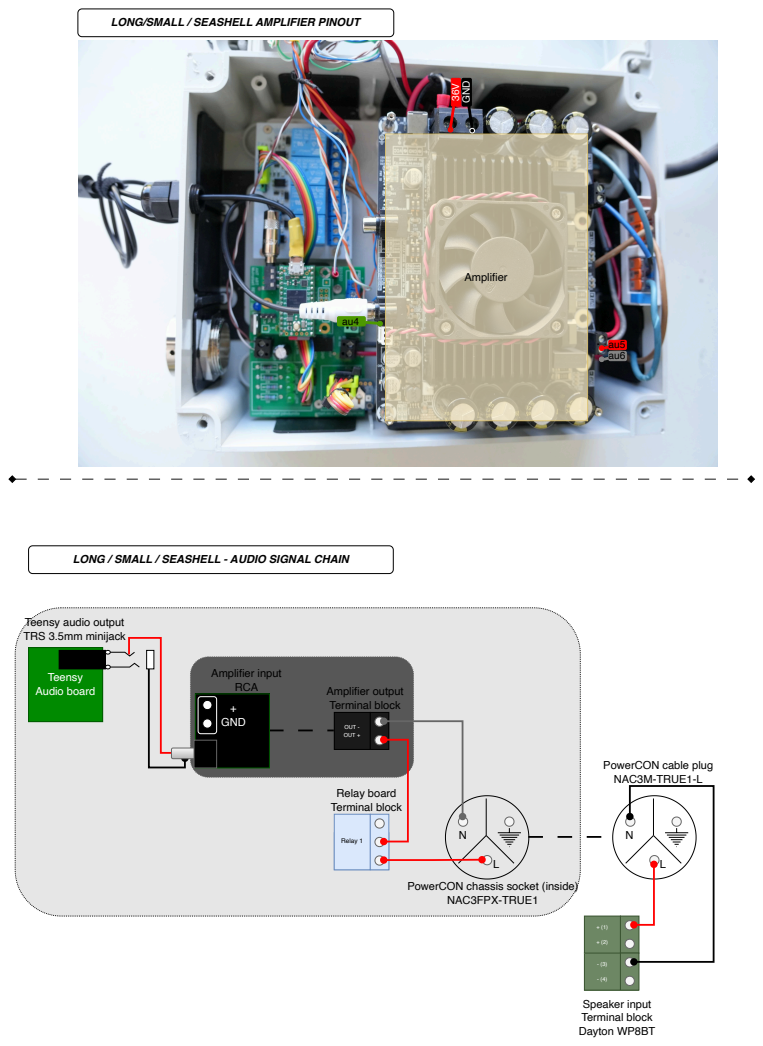
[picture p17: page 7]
Amplifier; GND; OUT -; OUT +; Relay 1; Amplifier output Terminal block; Relay board Terminal block; Speaker input Terminal block Dayton WP8BT; NAC3FPX-TRUE1; Teensy Audio board; Amplifier input RCA; + GND

LONG/SMALL / SEASHELL AMPLIFIER PINOUT

LONG / SMALL / SEASHELL - AUDIO SIGNAL CHAIN

Teensy audio output
TRS 3.5mm minijack

PowerCON cable plug
NAC3M-TRUE1-L

PowerCON chassis socket (inside)

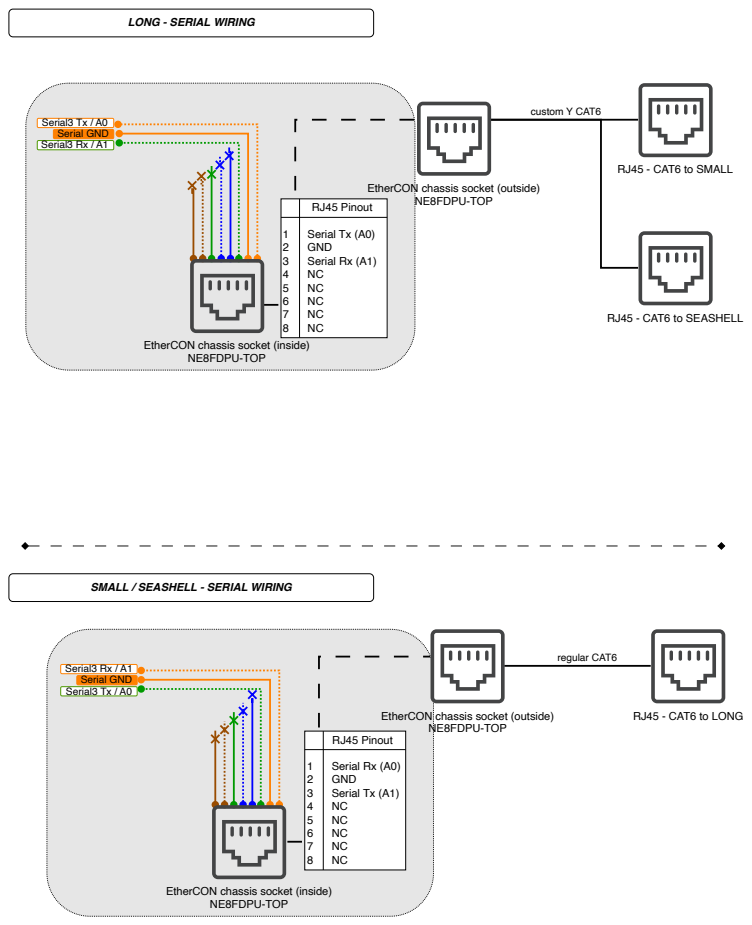
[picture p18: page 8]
NE8FDPU-TOP; RJ45 - CAT6 to SEASHELL; RJ45 - CAT6 to SMALL; custom Y CAT6; regular CAT6; RJ45 - CAT6 to LONG; RJ45 Pinout; Serial Rx (A0); GND; Serial Tx (A1); Serial Tx (A0); Serial Rx (A1); Serial3 Tx / A0 Serial GND Serial3 Rx / A1; Serial3 Rx / A1; Serial3 Tx / A0; Serial GND

LONG - SERIAL WIRING

EtherCON chassis socket (outside)

EtherCON chassis socket (inside)

SMALL / SEASHELL - SERIAL WIRING

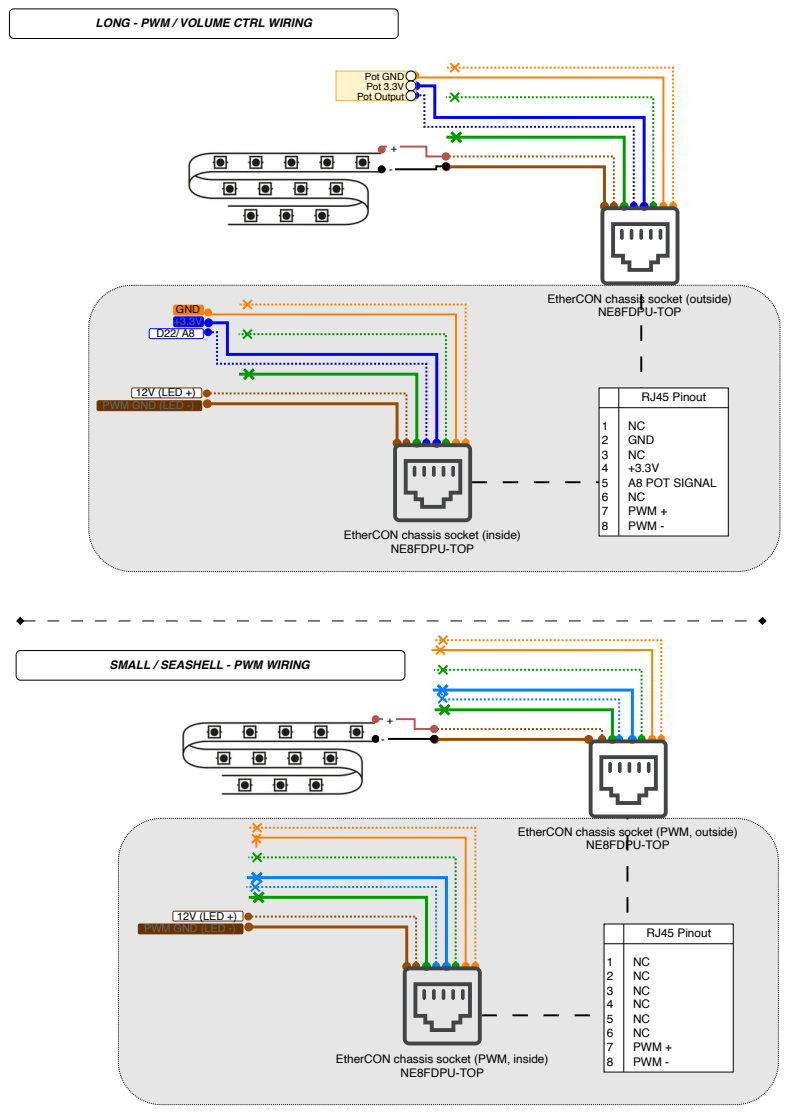
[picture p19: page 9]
NE8FDPU-TOP; RJ45 Pinout; GND; A8 POT SIGNAL; PWM +; PWM -; Pot GND Pot 3.3V Pot Output; EtherCON chassis socket (PWM, inside); GND +3.3V D22/ A8; 12V (LED +)

LONG - PWM / VOLUME CTRL WIRING

EtherCON chassis socket (outside)

PWM GND (LED -)

EtherCON chassis socket (inside)

SMALL / SEASHELL - PWM WIRING

EtherCON chassis socket (PWM, outside)

## TRS 3.5 minijack pinout

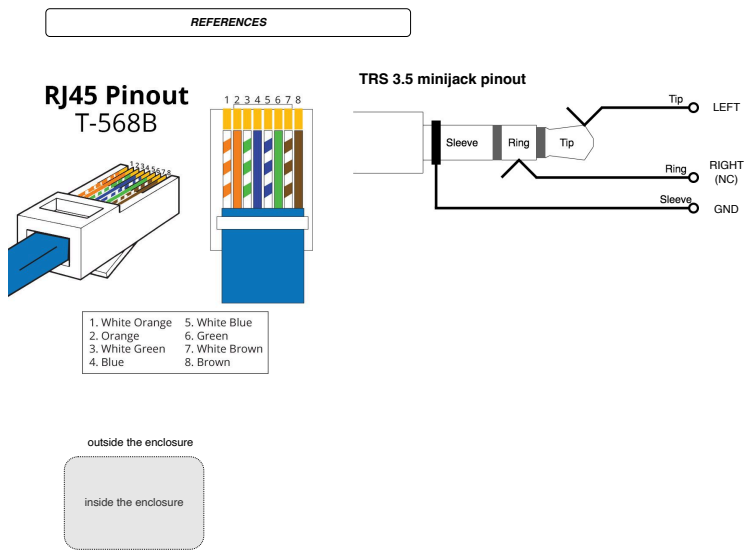
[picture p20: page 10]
REFERENCES; LEFT; RIGHT (NC); GND

outside the enclosure

inside the enclosure

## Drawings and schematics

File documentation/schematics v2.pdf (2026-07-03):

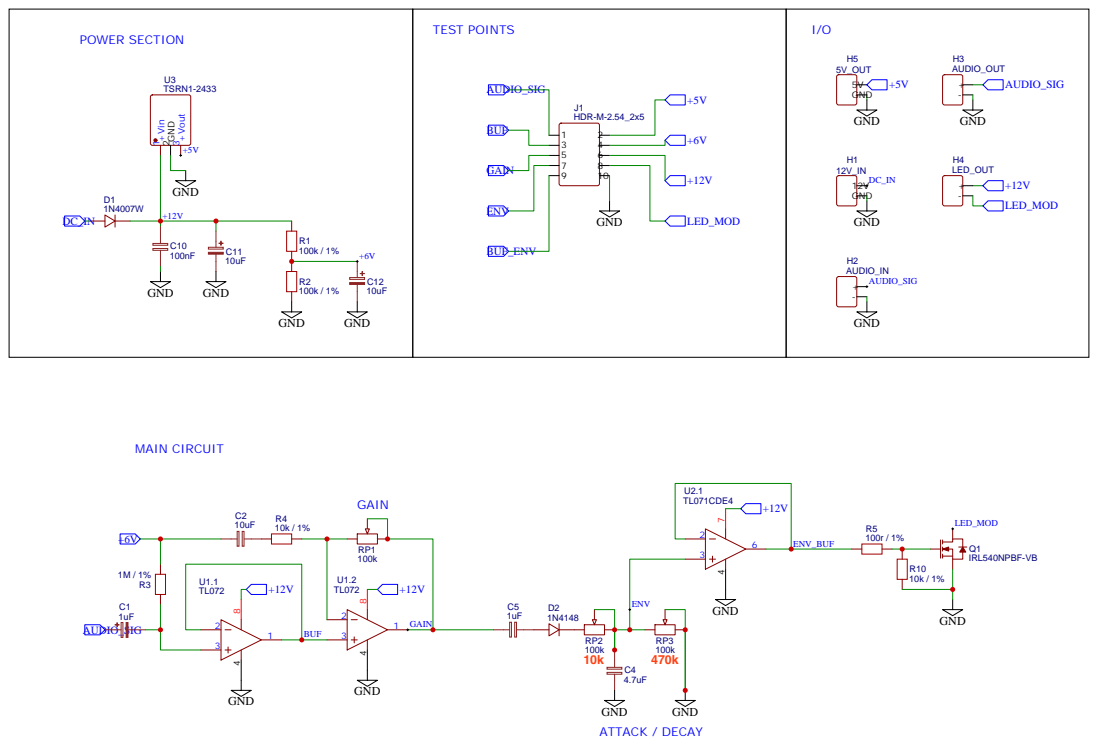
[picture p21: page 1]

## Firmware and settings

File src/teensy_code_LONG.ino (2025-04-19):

/*
  Sound to light system. Audio playback outputs audio RMS or peak values to PWM output, driving LED strip.
  3 players: 1 leader (LO short for LONG) has an RTC module and control 2 followers through Serial3 (SM for SMALL and SS for SEASHELL)

  PINS:
    0 x (must be NC, used for USB Serial)
    1 x (must be NC, used for USB Serial)
    2 LED_1
    3 LED_2
    4 LED_3
    5 LED_4
    6 PWM_OUT (LED strip control)
    7 x (can be used as receiver for Serial2)
    8 x (can be used as transmitter for Serial2)
    9 x
    10 SDCARD_CS_PIN (SD card)
    11 SDCARD_MOSI_PIN (SD card)
    12 x
    13 SDCARD_SCK_PIN (SD card)
    14 RX3 (receive serial on SM/SS, x on LO)
    15 TX3 (send serial on LO, x on SM/SS)
    16 REL_1 (relay PSU/amp)
    17 REL_2 (relay speaker)
    18 SDA0 (RTC on LO, x on SM/SS)
    19 SCL0 (RTC on LO, x on SM/SS)
    20 LRCLK1 (audio)
    21 BCLK1 (audio)
    22 VOL_CTRL_PIN (analog volume ctrl)
    23 MCLK (audio)
    28 PLAYED_ID (2, SS)
    30 PLAYER_ID (1, SM)
    32 PLAYER_ID (0, LO)

  CODES:
    0 x
    1 asleep
    2 awake and not playing
    3
    4
    5
    6
    7
    8 playing audio
    9
    10
    11
    12
    13
    14
    15 awake

  created 21.08.2024
  by Antoine "Arthur" Hureau-Parreira
  Ant Art Enk, Bergen NO

  This code relies on open-source technology and references and belongs to the public domain.
*/

#include <Audio.h>
#include <Wire.h>
#include <SPI.h>
#include <SD.h>
#include <SerialFlash.h>
#include <elapsedMillis.h>
#include <RTClib.h>
#include "LedzCtrl.h"       //custom lib for LEDs array control
#include "mySysCtrl.h"      //custom lib for system control

//OBJECTS
//audio
AudioPlaySdWav sdWav;
AudioAnalyzePeak audioPeak;
AudioAnalyzeRMS audioRMS;
AudioOutputI2S audioOutput;
AudioControlSGTL5000 sgtl5000;
//rtc
RTC_DS3231 rtc;

//AUDIO MATRIX
AudioConnection patchCord1(sdWav, 0, audioOutput, 0);
AudioConnection patchCord2(sdWav, 0, audioPeak, 0);
AudioConnection patchCord3(sdWav, 0, audioRMS, 0);

//SD CARD
const int SDCARD_CS_PIN = 10;
const int SDCARD_MOSI_PIN = 11;  //teensy uses 11 instead of 7
const int SDCARD_SCK_PIN = 13;   //teensy uses 13 instead of 14

//DIGITAL PINS
const int REL_1 = 16;
const int REL_2 = 17;
const int LED_1 = 2;
const int LED_2 = 3;
const int LED_3 = 4;
const int LED_4 = 5;
const int PWM_PIN = 6;
const int SMALL_PIN = 30;
const int SEASHELL_PIN = 28;
const int LONG_PIN = 32;

//ANALOG PINS
const uint8_t VOL_CTRL_PIN = A8;

//IO ARRAYS
const uint8_t LED_ARRAY[4] = { LED_1, LED_2, LED_3, LED_4 };

//SYSTEM
float audioVolume = 0.8;  //0-1, controls loudness
int rangePWM = 255;       //0-255, controls brightness
int currentCode = 0;      //starts at 0
int audioMemory = 8;
int startupDelay = 5000;   //inactivity time after setup for LONG player
int trackIteration = 0;    //resets every day at START_HOUR
const int START_HOUR = 6;  //daily wake-up time
const int END_HOUR = 23;   //daily sleep time
const int PWM_FREQ = 24;   //Hz, refresh rate for the PWM
const int REL_SW_DELAY = 500;
bool systemAwake = false;  //activity time between START_HOUR and END_HOUR
bool playbackStatus = false;
const bool PEAK_MODE = true;  //Switch between peak or rms mode

//RTC
const char days[7][12] = { "Sunday", "Monday", "Tuesday", "Wednesday", "Thursday", "Friday", "Saturday" };

//FILE NAMES AND PLAYER ID
const char SM_STR[13] = "SMALL.WAV";
const char SS_STR[13] = "SEASHELL.WAV";
const char LO_STR[13] = "LONG.WAV";
const char TEST_STR[19] = "LONG_TEST_LOOP.WAV";
char FILE_NAME[13] = "";
int PLAYER_ID;

//characters for serial commands
const char CMD_WAKEUP = 'W';
const char CMD_PLAY = 'P';
const char CMD_SLEEP = 'S';
const char CMD_MUTE = 'M';
const char CMD_LED_1 = 'A';
const char CMD_LED_2 = 'B';
const char CMD_LED_3 = 'C';
const char CMD_LED_4 = 'D';

//SETUP
void setup() {
  Serial.begin(9600);
  Serial3.begin(9600);

  setupPlayerID();

  for (int j = 0; j < 4; j++) {
    pinMode(LED_ARRAY[j], OUTPUT);
  }
  Serial.println("Leds array setup");

  pinMode(REL_1, OUTPUT);
  pinMode(REL_2, OUTPUT);
  Serial.println("Relays array setup");

  pinMode(PWM_PIN, OUTPUT);
  Serial.println("PWM and listen pins setup");

  //audio memory allocation, codec and volume setup
  AudioMemory(8);
  sgtl5000.enable();
  sgtl5000.volume(audioVolume);

  Serial.println("Audio memory allocated");

  // Configure SPI communication for the SD card
  SPI.setMOSI(SDCARD_MOSI_PIN);
  SPI.setSCK(SDCARD_SCK_PIN);

  Serial.println("SPI communication configures");
  Serial.println("SD card initialization...");

  // Check SD card accessibility
  if (!(SD.begin(SDCARD_CS_PIN))) {
    while (1) {
      Serial.println("Unable to access the SD card");
      delay(500);
    }
  } else {
    Serial.println("SD card loaded");
  }

  //help function to init RTC
  if (PLAYER_ID == 0) {
    setupRTC();
    Serial.println("RTC setup");

    //flag for initialization complete
    Serial.print("Setup complete! starting playback in ");
    Serial.print(startupDelay / 1000);
    Serial.println("s.");

    delay(startupDelay);  //wait for 2 other units to listen
  } else {
    //flag for initialization complete
    Serial.println("Setup complete! waiting for LONG player to playback.");
  }
}

//start millis thread timer
elapsedMillis fps;

//LOOP
void loop() {
  //testLoop();
  statusUpdates();
  checkSerialCommands();

  //LO player
  if (PLAYER_ID == 0) {
    leader();
  }

  // SM/SS player
  if (PLAYER_ID != 0) {
    follower();
  }
}


//###########################################################################
//helper function to setup the RTC module (adafruit documentation, details in "Examples > RTClib")
void setupRTC() {
  /*
  #ifndef ESP8266
    while (!Serial); // wait for serial port to connect. Needed for native USB
  #endif
  */

  if (!rtc.begin()) {
    Serial.println("Couldn't find RTC");
    Serial.flush();
    while (1) delay(10);
  }

  if (rtc.lostPower()) {
    Serial.println("RTC lost power, let's set the time!");
    rtc.adjust(DateTime(F(__DATE__), F(__TIME__)));
  }
}



/*
 * helper function to write pwm output from peak or rms 
 * @pin: Pin to write PWM output.
 * @peak: TRUE for peak mode, FALSE for RMS mode.
 */
void writeOutPWM(uint8_t pin) {
  int pwm;

  if (fps > PWM_FREQ) {
    if (PEAK_MODE) {  //peak mode
      if (audioPeak.available()) {
        fps = 0;
        pwm = audioPeak.read() * rangePWM;
        analogWrite(pin, pwm);
      }

    } else if (!PEAK_MODE) {  //RMS mode
      if (audioRMS.available()) {
        fps = 0;
        pwm = audioRMS.read() * rangePWM;
        analogWrite(pin, pwm);
      }
    }
  }
}

//helper function to control the audio volume
void volumeControl() {
  float val = analogRead(VOL_CTRL_PIN);
  audioVolume = val / 1024;  //10bits to 0-1 scale
  sgtl5000.volume(audioVolume);
}

//write simple commands to Serial3
void sendCommand(char cmd) {
  Serial3.write(cmd);
}

//helper function to manage audio playback
void playAudio() {
  sdWav.play(FILE_NAME);
  delay(10);
  trackIteration += 1;
  playbackStatus = true;
  Serial.print("Start playing ");
  Serial.println(FILE_NAME);
  Serial.print("Track iteration nr ");
  Serial.print(trackIteration);
  Serial.println(" during curent session (will be deleted tomorrow morning at 6AM).");
}

void fadeOut() {
  //stores current audio volume and pwm range values to retrieve afterwards
  const float tmpVolume = audioVolume;
  const int tmpPWM = rangePWM;

  const int stepTime = 10;                         //in ms
  const int steps = 1000 / stepTime;               //1s divided by step tipe
  const float stepPWM = tmpPWM / (float)steps;     //calculates 0-255 decrement rate per setp
  const float stepVol = tmpVolume / (float)steps;  //calculates 0-1 decrement rate per step

  //take decrement .01 each 10ms, over a second
  for (int i = 0; i < steps; i++) {
    audioVolume -= stepVol;
    rangePWM -= stepPWM;
    delay(stepTime);
  }

  //readjust values after fadeout loop is done
  audioVolume = tmpVolume;
  rangePWM = tmpPWM;
}

void leader() {
  if (systemAwake) {
    sendCommand(CMD_WAKEUP);
    displayBinaryCode(8);
    sendCommand(CMD_LED_4);

    if (!sdWav.isPlaying()) {
      delay(1000); //wait a second
      sendCommand(CMD_PLAY);
      playAudio();
      clockMe();
    }

    if (sdWav.isPlaying()) {
      writeOutPWM(PWM_PIN);
      //volumeControl();
    }
  }

  if (!systemAwake) {
    if (sdWav.isPlaying()) {
      writeOutPWM(PWM_PIN);
      //volumeControl();
    }
    if (!sdWav.isPlaying()) {
      sendCommand(CMD_SLEEP);
      sendCommand(CMD_LED_1);
      displayBinaryCode(1);
      digitalWrite(PWM_PIN, LOW);
    }
  }
}

void follower() {
  if (Serial3.available() > 0) {
    char incomingByte = Serial3.read();

    switch (incomingByte) {
      case CMD_LED_1:
        displayBinaryCode(1);
        break;

      case CMD_LED_2:
        displayBinaryCode(2);
        break;

      case CMD_LED_3:
        displayBinaryCode(4);
        break;

      case CMD_LED_4:
        displayBinaryCode(8);
        break;

      case CMD_PLAY:  //play
        if (sdWav.isPlaying()){
          sdWav.stop();
        }
        playAudio();
        break;

      case CMD_WAKEUP:  //wake-up
        if (!systemAwake) {
          startupSequence();
          systemAwake = !systemAwake;
          trackIteration = 0;
        }
        break;

      case CMD_SLEEP:  //sleep
        if (systemAwake) {
          shutDownSequence();
          systemAwake = !systemAwake;
        }
        break;

      case CMD_MUTE:  //mute
        audioVolume = 0;
        break;

      default:
        displayBinaryCode(0);
        break;
    }
  }

  if (systemAwake) {
    if (sdWav.isPlaying()) {
      writeOutPWM(PWM_PIN);
    }
  }
  if (!systemAwake) {
    digitalWrite(PWM_PIN, LOW);
  }
}

//if test mode
void testLoop() {
  if (!sdWav.isPlaying()) {
    startupSequence();
    testAudio();
  }

  while (sdWav.isPlaying()) {
    writeOutPWM(PWM_PIN);
  }
}

//helper function to manage audio playback
void testAudio() {
  sdWav.play(TEST_STR);
  delay(10);
  trackIteration += 1;
  Serial.print("Start playing test ");
  Serial.println(TEST_STR);
  Serial.print("Test iteration nr ");
  Serial.print(trackIteration);
  Serial.println(" during curent session (will be deleted tomorrow morning at 6AM).");
}

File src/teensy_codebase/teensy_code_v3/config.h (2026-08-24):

/**
 * config.h - compile-time configuration for Suuret Muinaiset (V3).
 *
 * PURPOSE
 *   Single source of truth for every pin, timing, threshold and protocol
 *   constant in the firmware. Nothing here allocates storage that varies at
 *   runtime: every value is constexpr, so it costs no RAM and may be used
 *   from any translation unit without a definition.
 *
 * WHY ONE FILE
 *   All three units run the same binary. The only thing that differs between
 *   them is which hardware ID strap pin is tied high, so every difference in
 *   behaviour has to be derivable from constants that are identical
 *   everywhere. Keeping them together makes that auditable: if a value is not
 *   in this file, it is not configuration.
 *
 * EDITING RULES
 *   Values here are read at compile time only. Changing one requires a
 *   rebuild and a re-upload to all three units, not just the leader.
 */
#ifndef SM_CONFIG_H
#define SM_CONFIG_H

#include <Arduino.h>

/**
 * Hardware watchdog toggle.
 *
 * With 1, any hang self-recovers after cfg::WDT_TIMEOUT_S. This requires the
 * third-party WDT_T4 library (tonton81) to be installed AND the board target
 * set to a Teensy 4.x. Watchdog_t4.h only declares WDT_T4 and WDT1 for the
 * i.MX RT chip, so building with a Teensy 3.x selected strips the header to
 * nothing and fails with "'WDT1' was not declared in this scope".
 *
 * With 0, every watchdog reference compiles out and the library is not
 * needed at all.
 *
 * A hang will NOT self-recover while this is 0.
 *
 * Kept at 0 deliberately (2026-08-24). Before setting this to 1, fix
 * Controller::setup(): WDT_timings_t is only partially initialized there, so
 * its remaining members - including any pretimeout callback pointer - are
 * stack garbage handed straight to wdt_.begin(). Change that declaration to
 * "WDT_timings_t t = {};" first. The UB is masked only while this is 0.
 */
#define USE_WATCHDOG 0

/**
 * Leader audio-health trace toggle.
 *
 * Gates the leader's 1 Hz Serial.printf trace in leaderTask() - the line that
 * reports playback position, peak audio-block usage and peak audio-ISR load
 * while a round is playing.
 *
 * With 0 the whole block compiles out and the USB console stays quiet, which
 * is what you want in normal field operation: the trace otherwise emits a line
 * every second for the entire playing day.
 *
 * Flip to 1 when chasing an audio or CPU problem, then read the output as
 * described in the README. mem climbing toward cfg::AUDIO_MEMORY_BLOCKS, or t
 * failing to advance by roughly 1000 between lines, means the SD path is
 * starving rather than the fault sitting downstream in the analog chain.
 */
#define AUDIO_TRACE 0

namespace cfg {

  /**
   * Hardware ID strap pins.
   *
   * Exactly one of these is tied HIGH on each unit's motherboard; that is
   * what selects the role, the WAV file and the serial address. The pins are
   * read once at boot with the internal pulldown enabled, so an unconnected
   * or broken strap reads LOW and is reported rather than floating to a
   * random role.
   */
  constexpr uint8_t PIN_LONG     = 32;   // leader
  constexpr uint8_t PIN_SMALL    = 30;   // follower 1
  constexpr uint8_t PIN_SEASHELL = 28;   // follower 2

  /**
   * Status LED array, MSB first: LED_PINS[0] is bit 3, LED_PINS[3] is bit 0.
   * The order matches the silkscreen so on-site reading of the array is
   * unchanged from the original build.
   */
  constexpr uint8_t LED_PINS[4]  = { 2, 3, 4, 5 };

  /**
   * Relays.
   *
   * REL_AMP switches mains to the 36V PSU that feeds the amplifier; REL_SPK
   * switches the amplifier output through to the speaker. They are sequenced
   * amp-then-speaker on wake and speaker-then-amp on sleep so the speaker is
   * never connected while the amplifier rail is settling, which is what would
   * otherwise produce a thump through the driver.
   *
   * RELAY_ACTIVE_LOW covers opto-isolated relay boards that energize on a LOW
   * output. Flip it if the relays click in at boot or behave inverted.
   */
  constexpr uint8_t  REL_AMP          = 17;
  constexpr uint8_t  REL_SPK          = 16;
  constexpr bool     RELAY_ACTIVE_LOW = false;
  constexpr uint16_t RELAY_DWELL_MS   = 500;   // settle time between switches
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

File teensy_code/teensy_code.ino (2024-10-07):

/*
  Audio playback on a timer, and output audio RMS or peak values to PWM output

  The circuit on a teensy 3.2:
	- pin 6 as a digital output, using PWM (analogWrite function)
	- pins 18 and 19 used as SCL and SPA for the RTC module (Adafruit 8523)
	- pwm output goes through an IRL520 MOSFET, that itself drives a LED strip.

  created 21.08.2024
  by Antoine "Arthur" Hureau-Parreira
  Ant Art Enk, Bergen NO

  This code relies on open-source technology and references and belongs to the public domain.
*/

#include <Audio.h>
#include <Wire.h>
#include <SPI.h>
#include <SD.h>
#include <SerialFlash.h>
#include <elapsedMillis.h>
#include "RTClib.h"

//OBJECTS
//audio
AudioPlaySdWav playSdWav1;
AudioAnalyzePeak audioPeak;
AudioAnalyzeRMS audioRMS;
AudioOutputI2S audioOutput;
AudioControlSGTL5000 sgtl5000_1;
//rtc
RTC_PCF8523 rtc;

//AUDIO MATRIX
AudioConnection patchCord1(playSdWav1, 0, audioOutput, 0);
AudioConnection patchCord2(playSdWav1, 0, audioPeak, 0);
AudioConnection patchCord3(playSdWav1, 0, audioRMS, 0);

//SD CARD
#define SDCARD_CS_PIN 10
#define SDCARD_MOSI_PIN 7
#define SDCARD_SCK_PIN 14

//PINS
const int PWM_PIN = 6;
const int RELAY_PIN = 16;
const uint8_t VOL_CTRL_PIN = A0;
const uint8_t PWM_CTRL_PIN = A1;

//VARIABLES
float audioVolume = 0.2;
int rangePWM = 255;
const bool PEAK_MODE = false;
char days[7][12] = {"Sunday", "Monday", "Tuesday", "Wednesday", "Thursday", "Friday", "Saturday"};
const int START_HOUR = 6;
const int END_HOUR = 23;
const char FILE_NAME[] = "SPIKY.wav"; //LONG.wav, SMALL.wav or SPIKY.wava depending on player

//SETUP
void setup() {
  Serial.begin(57600);

  //audio memory allocation, codec and volume setup
  AudioMemory(8);
  sgtl5000_1.enable();
  sgtl5000_1.volume(audioVolume);

  // Configure SPI communication for the SD card
  SPI.setMOSI(SDCARD_MOSI_PIN);
  SPI.setSCK(SDCARD_SCK_PIN);
  
  // Check SD card accessibility
  if (!(SD.begin(SDCARD_CS_PIN))) {
    while (1) {
      Serial.println("Unable to access the SD card");
      delay(500);
    }
  } else {
    Serial.println("SD card loaded");
  }

  //Declare pins
  pinMode(PWM_PIN, OUTPUT);
  pinMode(RELAY_PIN, OUTPUT);

  //help function to init RTC
  setupRTC();

  //flash light 4 times at startup (1 sec)
  for (int i=0; i < 4; i++){
    analogWrite(PWM_PIN, 1);
    delay(50);
    analogWrite(PWM_PIN, 0);
    delay(50);
  }
  
  //flag for initialization complete
  Serial.println("Initialized");
}


//start millis thread timer
elapsedMillis fps;

//LOOP
void loop() {
  if (rtc.now().hour() >= START_HOUR){
      if (rtc.now().hour() <= END_HOUR){

        digitalWrite(RELAY_PIN, HIGH);
        if (playSdWav1.isPlaying() == false) {
          Serial.print("Start playing ");
          Serial.println(FILE_NAME);
          playSdWav1.play(FILE_NAME);
        }
        //while playing
        while (playSdWav1.isPlaying() == true) {
          writeOutPWM(PWM_PIN, PEAK_MODE);
          volumeControl();
          //pwmControl();
        }
        clockMe();
        }
    }

  else{
    digitalWrite(RELAY_PIN, LOW);
    analogWrite(PWM_PIN, 0);
    Serial.print("I'm asleep. ");
    Serial.print(FILE_NAME);
    Serial.print(" will play again from ");
    Serial.println(START_HOUR);
    clockMe();
  }

}

//###########################################################################
//helper function to setup the RTC module (adafruit documentation, details in "Examples > RTClib > pcf8523")
void setupRTC(){
  //comment-out the 3 next lines when not on USB
  /*
  #ifndef ESP8266
  while (!Serial); // wait for serial port to connect. Needed for native USB
  #endif
  */
  
  if (! rtc.begin()) {
    Serial.println("Couldn't find RTC");
    Serial.flush();
    while (1) delay(10);
  }

  if (! rtc.initialized() || rtc.lostPower()) {
    Serial.println("RTC is NOT initialized, let's set the time!");

    rtc.adjust(DateTime(F(__DATE__), F(__TIME__)));

  }

  //uncomment next line to update RTC time
  //If used, be sure to compile 2 times! first with the line uncommented setup the RTC, a second time with the line commented
  //rtc.adjust(DateTime(F(__DATE__), F(__TIME__)));
  rtc.start();

  float drift = 43;
  float period_sec = (7 * 86400);
  float deviation_ppm = (drift / period_sec * 1000000);
  float drift_unit = 4.34;
  int offset = round(deviation_ppm / drift_unit);

  clockMe(); //print date and time
  Serial.print("Offset is "); // Print offset time
  Serial.println(offset); // Print offset time
}

//helper function to print time
void clockMe(){
  DateTime input = rtc.now();
  Serial.print(input.year(), DEC);
  Serial.print('/');
  Serial.print(input.month(), DEC);
  Serial.print('/');
  Serial.print(input.day(), DEC);
  Serial.print(" (");
  Serial.print(days[input.dayOfTheWeek()]);
  Serial.print(") ");
  Serial.print(input.hour(), DEC);
  Serial.print(':');
  Serial.print(input.minute(), DEC);
  Serial.print(':');
  Serial.print(input.second(), DEC);
  Serial.println();
  delay(1000);
}

/*
 * helper function to write pwm output from peak or rms 
 * @pin: Pin to write PWM output.
 * @peak: TRUE for peak mode, FALSE for RMS mode.
 */
void writeOutPWM(int pin, bool peak){
  int pwm;

  if (fps > 24) {
    if (peak == true){ //peak mode
      if (audioPeak.available()) {
        fps = 0;
        pwm = audioPeak.read() * rangePWM;
        analogWrite(pin, pwm);
      }

    } else if (peak == false) { //RMS mode±
      if (audioRMS.available()) {
        fps = 0;
        pwm = audioRMS.read() * rangePWM;
        analogWrite(pin, pwm);
      }
    }
  }
}

//helper function to control the audio volume
void volumeControl(){
  float val = analogRead(VOL_CTRL_PIN);
  audioVolume = val / 1024; //10bits to 0-1 scale
  sgtl5000_1.volume(audioVolume);
}

//helper function to control the PWM range
void pwmControl(){
  int val = analogRead(PWM_CTRL_PIN);
  rangePWM = val / 4; //10bits to 0-255 scale
}

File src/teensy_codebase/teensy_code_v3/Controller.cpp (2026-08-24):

/**
 * Controller.cpp - role detection and the leader/follower state machines.
 * See Controller.h for the architecture and why nothing here blocks.
 */
#include "Controller.h"
#include <math.h>

/* ===========================================================================
 * ROLE
 *
 * Decided once at boot from the hardware ID straps and never revisited. Every
 * per-unit difference in behaviour derives from this one reading.
 * ========================================================================= */

Role Controller::detectRole() {
  /*
   * Internal pulldowns matter here. With a plain INPUT a disconnected strap
   * floats and can read HIGH, which would let a follower decide it is the
   * leader - putting two transmitters on the shared back-channel. Pulled down,
   * a broken strap reads LOW and falls through to the reported default.
   */
  pinMode(cfg::PIN_LONG,     INPUT_PULLDOWN);
  pinMode(cfg::PIN_SMALL,    INPUT_PULLDOWN);
  pinMode(cfg::PIN_SEASHELL, INPUT_PULLDOWN);

  if (digitalRead(cfg::PIN_LONG)     == HIGH) return Role::LEADER;
  if (digitalRead(cfg::PIN_SMALL)    == HIGH) return Role::SMALL;
  if (digitalRead(cfg::PIN_SEASHELL) == HIGH) return Role::SEASHELL;

  /*
   * No strap read high. Defaulting to leader keeps a single unit on a bench
   * useful, but on site it means a strap has failed - so say so loudly rather
   * than letting it pass as normal.
   */
  Serial.println(F("WARNING: no ID strap detected, defaulting to LEADER"));
  return Role::LEADER;
}

/**
 * Return the WAV file name for this unit's role. The leader plays a long
 * file, the followers play their own short files. The file is never changed
 * after boot, so the leader can schedule rounds without asking the followers.
 * @param role The role to query.
 * @return The file name for the role, or "" if the role is unknown.
 */
const char *Controller::fileForRole() const {
  switch (role_) {
    case Role::SMALL:    return cfg::FILE_SMALL;
    case Role::SEASHELL: return cfg::FILE_SEASHELL;
    default:             return cfg::FILE_LONG;
  }
}

/**
 * Return the address for this unit's role. The leader is '0', the followers
 * are '1' and '2'. The address is never changed after boot, so the leader
 * can schedule rounds without asking the followers. The address is used in
 * the back-channel protocol to decide whether an incoming frame applies to
 * this unit.
 * @param role The role to query.
 * @return The address for the role, or '0' if the role is unknown.
 */
char Controller::myAddr() const {
  switch (role_) {
    case Role::SMALL:    return proto::ADDR_SMALL;
    case Role::SEASHELL: return proto::ADDR_SEASHELL;
    default:             return proto::ADDR_LEADER;
  }
}

/* ===========================================================================
 * WATCHDOG
 * ========================================================================= */

 /**
  * Feed the watchdog. The watchdog is enabled at boot and fed throughout
  * loop() and during any blocking operations, so a slow subsystem cannot
  * trip it. The watchdog is disabled at compile time for development builds
  * to avoid a crash loop when stepping through code.
  */
void Controller::feedWdt() {
#if USE_WATCHDOG
  wdt_.feed();
#endif
}

/* ===========================================================================
 * SETUP
 * ========================================================================= */

 /**
  * Initialize the controller and all subsystems. Called once at boot.
  * The watchdog is enabled at boot and fed throughout setup() and loop(),
  * so a slow subsystem cannot trip it. The watchdog is disabled at compile
  * time for development builds to avoid a crash loop when stepping through code.
  */
void Controller::setup() {
  /*
   * Baud is ignored on the Teensy's USB serial, which always runs at native
   * USB speed. It matters for Serial3, where 9600 is slow but ample: the
   * longest frame is well under 64 bytes and the link carries a few frames a
   * minute over a long buried cable, where slower is more forgiving.
   */
  Serial.begin(9600);
  link_.begin(9600);

  /* Surviving crash data from the previous run, if any. */
  if (CrashReport) { Serial.print("Crash: "); Serial.println(CrashReport); }

  role_ = detectRole();
  file_ = fileForRole();
  Serial.print("Role "); Serial.print((int)role_);
  Serial.print(" file "); Serial.println(file_);

  leds_.begin();
  relays_.begin();

  /*
   * Light output. The frequency is set above the audible band before anything
   * is written: the Teensy 4 default of roughly 4.5 kHz is heard as a whine
   * through the shared ground that tracks LED brightness.
   */
  pinMode(cfg::PWM_PIN, OUTPUT);
  analogWriteFrequency(cfg::PWM_PIN, cfg::PWM_FREQ_HZ);
  analogWriteResolution(8);
  analogWrite(cfg::PWM_PIN, 0);

  /*
   * Init is non-fatal: report what failed and carry on. The LED array is not
   * written here - announceFaults() does it at the end of setup, because
   * anything shown now would be overwritten by the first pass of loop().
   */
  audio_.begin(cfg::DEFAULT_VOLUME);
  if (!audio_.codecReady()) Serial.println("codec fail");
  if (!audio_.sdReady())    Serial.println("SD fail");

  if (role_ == Role::LEADER) {
    if (!rtc_.begin()) Serial.println("RTC fail");
  }

#if USE_WATCHDOG
  WDT_timings_t t;
  t.trigger = cfg::WDT_TIMEOUT_S;
  wdt_.begin(t);
#endif

  Serial.println("Setup complete.");

  /* Last thing before loop() takes over the display. */
  announceFaults();
}
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

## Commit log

2024-10-07 teensy code uploaded
2025-04-10 fixed audio playback
    pins 20, 21 and 23 cannot be used for relays and trigger line, so they are commented out and audio is back.
    [teensy_code_LONG.ino]
2025-04-11 trigger send receive
    change variables to only 1 trigger pin; functions to send and receive
2025-04-14 sync in place using serial3 + led array fixed
    must write test and debugs, add possibility to update volume from LONG to small and seashell ++
    [teensy_code_LONG.ino]
2025-04-15 added system report, fixed a few things here and there
    [teensy_code_LONG.ino]
2025-04-19 library implementation
    implementation of mySysControl.h for system control and LedzCtrl.h for the LEDs array control
2025-04-19 moved code to platformIO
    remains original "arduino" folder for ref
2025-04-27 flowchart documentation + media
2025-05-06 rework serial to avoid stack overflow
    recurring crash reports:
    CrashReport:
    A problem occurred at (system time) 0:6:37
    Code was executing from address 0x35E4
    CFSR: 82
    (DACCVIOL) Data Access Violation
    (MMARVALID) Accessed Address: 0x20004780 (Stack problem)
    Check for stack overflows, array bounds, etc.
    Temperature inside the chip was 62.29 °C
    Startup CPU clock speed is 600MHz
    Reboot was caused by auto reboot after fault or bad interrupt detected
    that led to rework on the whole serial command management
    [mySysCtrl.h, teensy_code.ino]
2025-05-06 update statusUpdate to print less info
2025-05-07 debuging stack overflow problems further
    [mySysCtrl.h, teensy_code.ino]
2025-05-07 crashes fixed by swapping sd cards and slowing system down
    [mySysCtrl.h, teensy_code.ino]
2025-05-07 no stack problem crashes anymore
    [mySysCtrl.h, teensy_code.ino]
2025-05-08 error handling during setup + comments
    [teensy_code.ino]
2025-05-10 update flowchart
2025-05-10 fixed LED stying on when going to sleep
    [main.cpp, mySysCtrl.h, teensy_code.ino]
2025-05-10 software reboot implemented
    every sunday midnight / monday 00:00 theres a software reboot as in SCB_AIRCR = 0x05FA0004;
    [mySysCtrl.h, teensy_code.ino]
2025-05-10 fixed method orders in system control .h
    [mySysCtrl.h]
2025-05-10 comments doc and small fixes
    [mySysCtrl.h, teensy_code.ino]
2025-05-11 added volume control and command for usb/knob volume control and command for reboot
    [mySysCtrl.h, teensy_code.ino]
2025-05-22 pin labels in flowchart doc
2025-05-23 labelling connections in flowchart doc
2025-05-23 labels flowchart doc
2025-05-24 flowchart doc labelling
2025-05-24 create flowchart2
2025-05-27 Update teensy_code.ino
    Updated wake-up and sleep times
2025-06-01 flowchart update
2025-06-01 Create flowchart diagram.pdf
2025-06-04 update flowchart diagram
2025-06-04 Update flowchart diagram.pdf
2025-06-25 updated file structure + 3d prints stl included
    [All TPU Gaskets.stl, Double 3-ways Wago holder.stl, Ethercon TPU gasket.stl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]
2025-09-29 fixed potential RTClostpower issue
    [teensy_code.ino]
2026-02-17 RTC setup update rtc lost power situation
2026-02-17 Refactor .h files to proper C++ structure with separate .cpp files
    Move function definitions from ledzCtrl.h and mySysCtrl.h into new
    ledzCtrl.cpp and mySysCtrl.cpp files, keeping only declarations and
    prototypes in the headers. This follows standard C/C++ convention of
    separating declarations from implementations.
2026-02-17 Fix UTF-8 degree symbols causing stray \302 compile error
    Replace literal °C (UTF-8 0xC2 0xB0) with \xB0 hex escape in
    Serial.println calls to ensure cross-platform compilation.
    [mySysCtrl.cpp]
2026-06-15 updating system to be PD/Rpi based instead of using 3 teensys
2026-06-16 added underscores to files structure to prevent bug from spaces in rpi and pd setup
    [RTC_setup_code.ino, mySysCtrl.cpp, mySysCtrl.h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]
2026-06-16 STOP_ALL button doesnt retrigger OPEN_ALL and PLAY_ALL
2026-06-17 moved audio files under pd_codebase directory. New prints while patch is running
2026-06-17 moved 3D prints directory under documentation
    [All TPU Gaskets.stl, Double 3-ways Wago holder.stl, Ethercon TPU gasket.stl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]
2026-06-17 pd patch update with many features. subpatches for each sub-function, better GUI and better prints when running in headless/nogui mode.
2026-06-17 update readme to match raspberry pi
2026-06-17 Revise README with updated system details and status
    Updated the overview and hardware/software requirements for the system. Added details on the audio-to-light circuit and current project status.
2026-06-17 Revise README with detailed system setup information
    Updated sections on signal path, audio-to-light circuit, Pure Data patch, sleep/wake schedule, autostart, daily cycle, and toolkit for maintenance.
2026-06-17 Revise audio-to-light circuit status in README
    Updated the audio-to-light circuit section to indicate that it is in progress and removed the detailed status update.
2026-06-18 switched pd_codebase direcotry name to src
2026-06-26 cleaned up teensy legacy codebase
2026-06-26 Revise README for clarity and detail enhancements
    Updated technical details for the audio-to-light circuit and other components in the README.
2026-06-26 schematics for sound to light circuit
2026-07-03 Update schematics v2.pdf
2026-08-06 src structure changed, readme reset
    [AudioEngine.cpp, Controller.cpp, RTC_setup_code.ino]
2026-08-12 Consolidate docs to root README; add AUDIO_TRACE and boot fault codes
    Documentation
    -------------
    Merge the firmware README into the root README, which becomes the single
    document for the system. Rewrite the whole file to the ASD-STE100
    (Simplified Technical English) writing rules: descriptive sentences of 25
    words or fewer, procedural sentences of 20 or fewer, paragraphs of six
    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
2026-08-19 v4 to track down error at address 0x60002526
    [AudioEngine.cpp, Controller.cpp]
2026-08-24 Restore v3 entry-point and config docs from main; drop v4 tree
    teensy_code_v3.ino and config.h were resolved to the older baseline side in
    the ee9b9f1 merge, rolling back main's documentation pass. Both files are
    taken from main again.
    USE_WATCHDOG stays 0 deliberately: Controller::setup() declares
    WDT_timings_t without initializing it, so enabling the watchdog hands
    stack garbage to wdt_.begin(). Noted in config.h next to the toggle.
    teensy_code_v4/ removed - the fault it was written to chase is host-side
    (a USB host sending the 134-baud reboot request), not a firmware bug.
    FaultHandler.{h,cpp} remain recoverable from commit 0c6e47f.
    [AudioEngine.cpp, Controller.cpp]
